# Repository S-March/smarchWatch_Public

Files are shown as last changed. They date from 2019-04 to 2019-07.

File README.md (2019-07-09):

# smarchWatch_PUBLIC

I decided sometime last year that I wanted to make a smart watch from scratch. I am an electrical engineer and product designer by day, so this was a fun side project that had been rolling around in my head for a while now. For future projects and progress pictures feel free to follow me on instagram @SamsonMarch

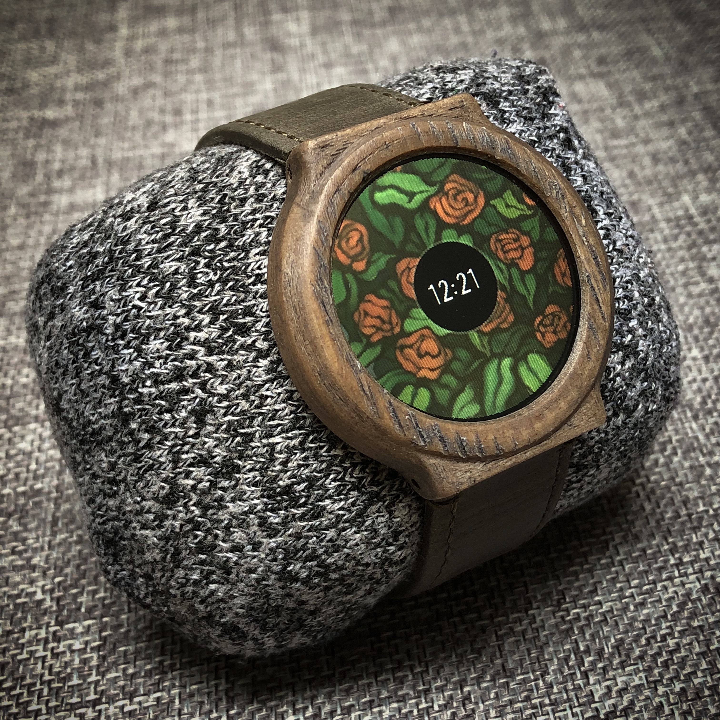
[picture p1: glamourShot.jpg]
smarchWatch


## Other Useful Links
To download the SDK for the DA14683, you can [click this link](https://support.dialog-semiconductor.com/system/files/restricted/DA1468x_DA15xxx_SDK_1.0.14.1081.zip)

If you want to order PCBs from the same place I did, you can [click this link](https://www.pcbway.com/project/shareproject/smarchWatch.html).

For more info on the build process and a blog describing the process, [click here](https://imgur.com/a/FSBwD3g).

For any ideas or things you wish could be in the project, comment on the issue [here](https://github.com/S-March/smarchWatch_PUBLIC/issues/15)

If you are interested in getting the soldered or barebones PCB, follow [this](https://github.com/S-March/smarchWatch_PUBLIC/issues/8) issue created by [vanabluca](https://github.com/vanbluca)

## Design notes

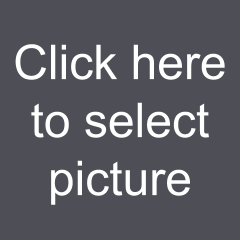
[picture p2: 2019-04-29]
Software/bitmapToArray/bitmapToArray/bitmapToArray/defaultPicture.png

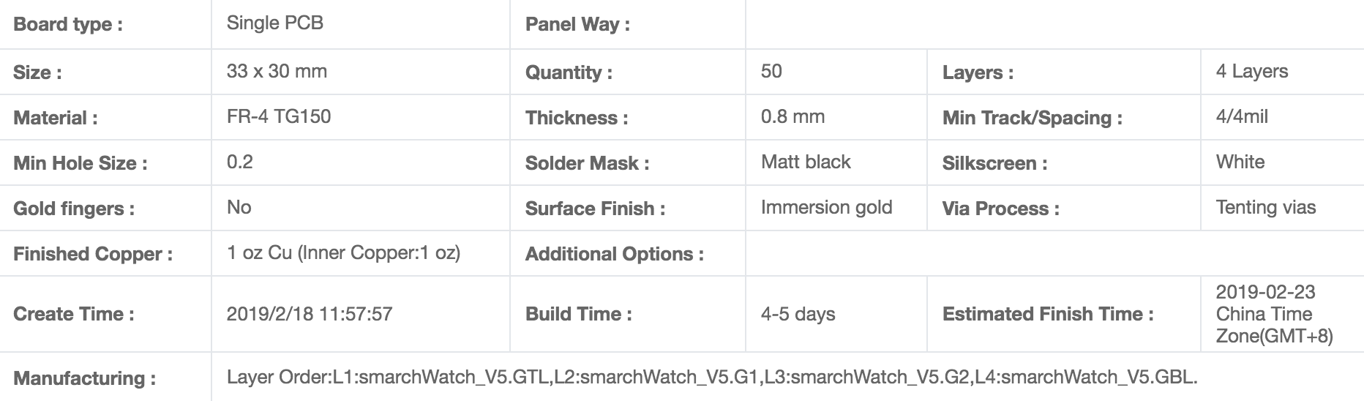
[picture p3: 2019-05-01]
PCB Files/Watch/Board parameters.png

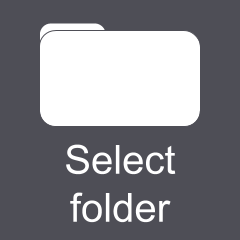
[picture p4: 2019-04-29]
Software/bitmapToArray/bitmapToArray/bitmapToArray/selectFolder.png

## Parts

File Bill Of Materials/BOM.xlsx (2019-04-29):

Comment | Description | Designator | Quantity | Part number | Digikey Number
10K | 0603 Resistor | R1, R3, R4, R5, R11 | 5 | RC0603FR-0710KL | 311-10.0KHRCT-ND
10uF | 0603 Capacitor | C2, C10, C11, C12, C15 | 5 | GRM188R61A106KE69D | 490-10474-1-ND
4.7uF | 0603 Capacitor | C3, C8, C9, C13 | 4 | CL10A475KP8NNNC | 1276-1044-1-ND
1uF | 0603 Capacitor | C4, C6, C7 | 3 | CL10B105KP8NNNC | 1276-1946-1-ND
100nF | 0603 Capacitor | C1, C5, C14 | 3 | CC0603KRX7R9BB104 | 311-1344-1-ND
5.1M | 0603 Resistor | R8, R9 | 2 | RC0603JR-075M1L | 311-5.1MGRCT-ND
330 Ohm | 0603 Resistor | R6, R10 | 2 | RC0603FR-07330RL | 311-330HRCT-ND
ECH8693R-TL-W | Mosfet Array 2 N-Channel (Dual) Common Drain 24V 14A 1.4W Surface Mount SOT-28FL/ECH8 | Q1, Q2 | 2 | ECH8693R-TL-W | ECH8693R-TL-WOSCT-ND
0 Ohm | 0603 Resistor | R13 | 1 | RC0603JR-070RL | 311-0.0GRCT-ND
0.1 Ohm | 0603 Resistor | R2 | 1 | RU1608FR100CS | 1276-6155-1-ND
0.39 Ohm | 0805 Resistor | R12 | 1 | RC0805FR-07390RL | 311-390CRCT-ND
2.2K | 0603 Resistor | R7 | 1 | RC0603FR-072K2L | 311-2.20KHRCT-ND
7M-16.000MEEQ-T | 16MHz ±10ppm Crystal 10pF 80 Ohms 4-SMD, No Lead | Y2 | 1 | 7M-16.000MEEQ-T | 887-1319-1-ND
9HT11-32.768KDZB-T | 32.768kHz ±20ppm Crystal 6pF 90 kOhms 2-SMD, No Lead | Y1 | 1 | 9HT11-32.768KDZB-T | 887-2616-1-ND
800-10-002-30-507101 | 2 Position Spring Mating Target Connector Surface Mount | P1 | 1 | 800-10-002-30-507101 | 1212-1446-ND
AML130A2402A | AML130A2402A Round 1.3" TFT Display | U1 | 1 | AML130A2402A | Dhgate.com
BQ29700DSER | Battery Battery Protection IC Lithium-Ion/Polymer 6-WSON (1.5x1.5) | U5 | 1 | BQ29700DSER | 296-43985-1-ND
C0720B001F | DC Motor Vibration, ERM 10000 RPM 3VDC | M1 | 1 | C0720B001F | 1670-1000-ND
CKP2012NR47M-T | Inductor_0805 | L1 | 1 | CKP2012NR47M-T | 587-2768-1-ND
DA14683 | SmartBond DA14683 Single-chip high-security Bluetooth 5 solution with expandable memory | U3 | 1 | DA14683-00000A92 | DA14683-00000A92CT-ND
ESD9B5.0ST5G | TVS DIODE 5V SOD923 | D1 | 1 | ESD9B5.0ST5G | ESD9B5.0ST5GOSCT-ND
LIS3DH | LIS3DH ACCEL 2-16G I2C/SPI 16LGA | U2 | 1 | LIS3DHTR | 497-10613-1-ND
RJD2430C1ST1 | Coin, 24.5mm 3.7V Lithium-Ion Battery Rechargeable (Secondary) 110mAh | BAT1 | 1 | RJD2430C1ST1 | 1572-1630-ND
W25Q128JVPIQ | FLASH - NOR Memory IC 128Mb (16M x 8) SPI - Quad I/O, QPI, DTR 133MHz 8-WSON (6x5) | U4 | 1 | W25Q128JVPIQ TR | W25Q128JVPIQCT-ND
PCB | PCB | N/A | 1 | N/A | N/A

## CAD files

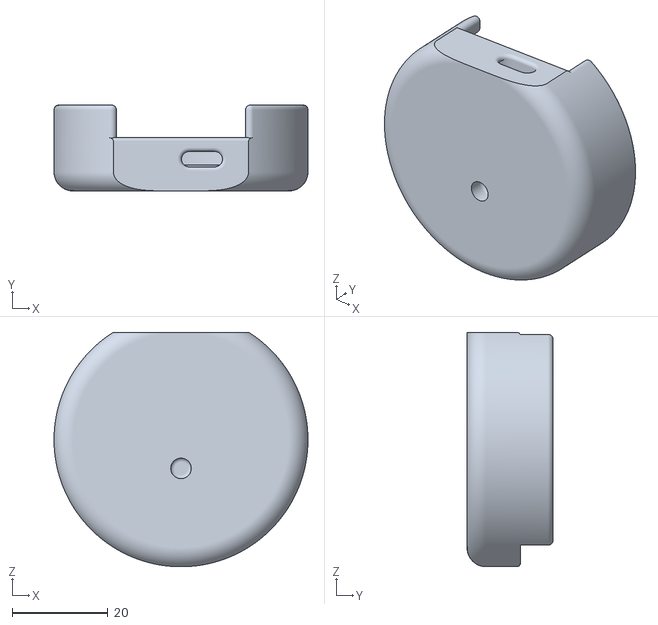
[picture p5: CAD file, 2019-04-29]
Housing/Charger/mainChargerBottom16mmBoard v13.stl
53.2 x 18.0 x 49.1

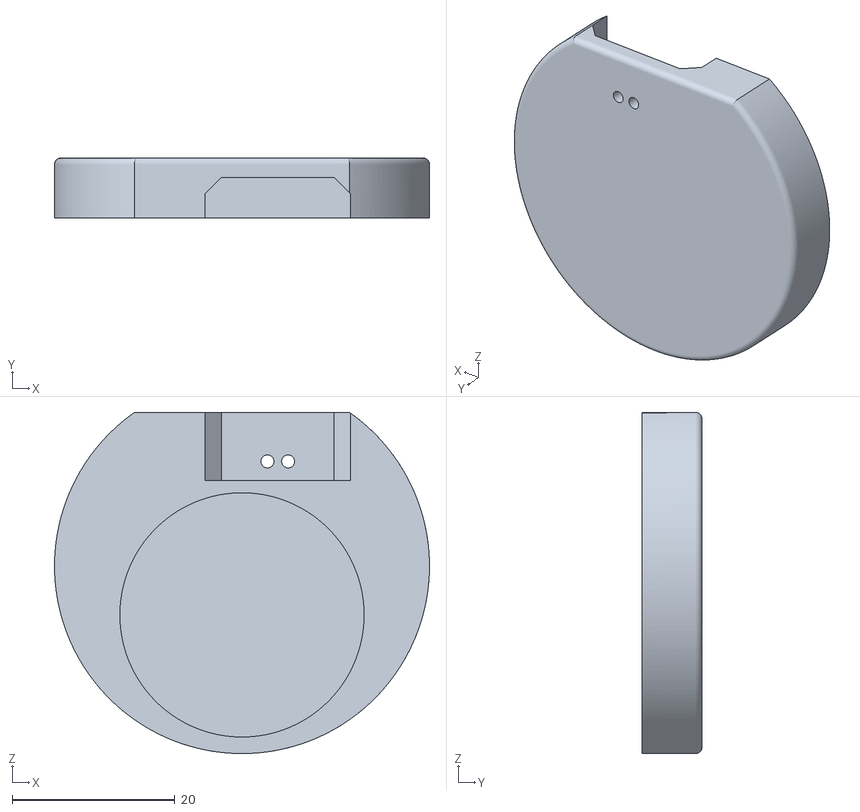
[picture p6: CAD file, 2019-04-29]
Housing/Charger/mainChargerTop v7.stl
46.1 x 7.40 x 41.9

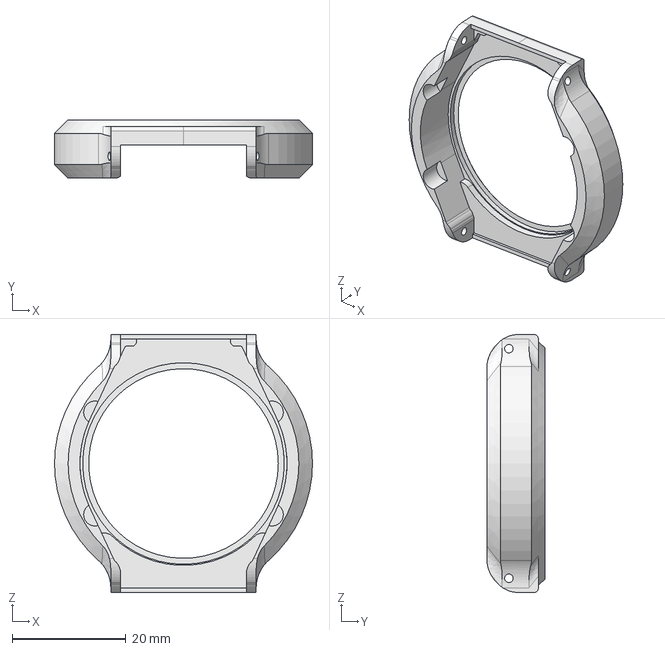
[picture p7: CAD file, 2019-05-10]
Housing/Body/bodyTop22mm_3.stp
45.5 x 10.3 x 45.5 mm

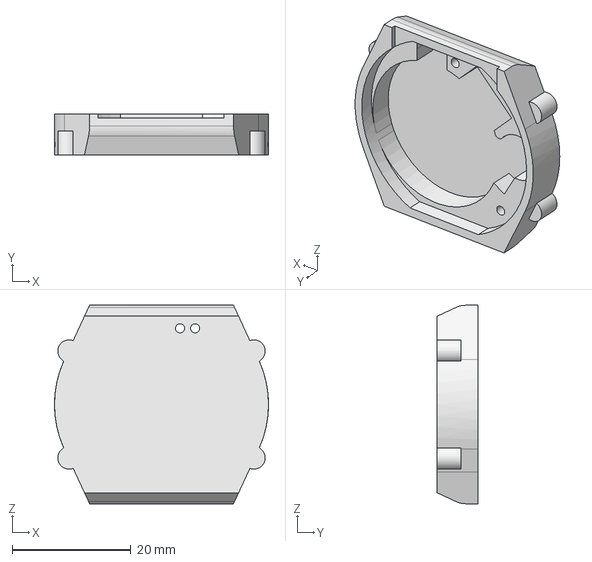
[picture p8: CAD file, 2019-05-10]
Housing/Body/bodyBottom22mm_3.stp
36.1 x 6.89 x 33.5 mm

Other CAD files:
Housing/Body/bodyBottom22mm_3.stl
Housing/Body/bodyTop22mm_3.stl

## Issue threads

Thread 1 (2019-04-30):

STEP/STP or IGES/IGS housing files?

justinclift, 2019-04-30:
Pretty nifty project. :smile:

With the housing files, any chance of STEP or IGES?

STL's are good for some things (eg 3D printing), but STEP or IGES include the model data, so are better for interchange with other cad software.

eg people can productively load a step or iges file in (say) FreeCAD and usefully modify it. :smile:

amishHammer, 2019-04-30:
Even and export of the Fusion F3D file would be helpful!!

vanbluca, 2019-05-01:
You can use the grabcad workbench to export the files in other formats really easily.

S-March, 2019-05-01:
I should be able to export them later tonight and put them up here!

S-March, 2019-05-01:
Didn't mean to close it. I will upload the files later tonight.

amishHammer, 2019-05-10:
> You can use the grabcad workbench to export the files in other formats really easily.

Yeah that's only good if you have a real solid model to put into grabcad.  With just the step file you can't do much conversion.

justinclift, 2019-05-10:
> With just the step file you can't do much conversion.

Typo?  The step file should be a solid model, whereas the stl file isn't real useful.

Well, as far as I understand anyway. :smile:

S-March, 2019-05-10:
Sorry I am just getting to this. The step files are now committed.

justinclift, 2019-05-10:
No worries at all @S-March, thanks for taking the time to get this stuff online. :grinning:

Closed 2019-05-10.

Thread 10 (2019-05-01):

Boom!

zerosimms, 2019-05-01:
This looks awesome!
Thank you so much for sharing and congrats on the Engadget publication!

Just one question, for the PCB board, can you tell me roughly how much it will cost? Or where I should begin to find out for myself - I can see it's not an "off the shelf" component and I'm assuming I would need to provide the PCB files to a manufacturer somewhere?

Sorry for the newbie question but normally I buy off the shelf, this part is all new to me.

Cheers

vanbluca, 2019-05-01:
I am looking into ordering a larger amount of PCBs at once to cut the costs. I already got some interested people. I expect 2pcs will be about $10 including shipping. Let me know in case you want one (or a few). I already got some interested people.

zerosimms, 2019-05-02:
Thanks, @vanbluca - I'd be very interested in purchasing, I'll wait for you ebay link :) Cheers!

Closed 2019-05-02.

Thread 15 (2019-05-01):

Wish list

S-March, 2019-05-01:
I thought it might be worth adding a wish list here for features that people might want. I may not have time to implement all of them, but maybe others in the community can!

vanbluca, 2019-05-01:
Would love a video on how to put your codes in the actual PCB.

Piflyer, 2019-05-01:
Hi, first off, congrats on creating this smartwatch! I lost mines, and I am desperate to find a replacement. I do like doing DIY crafts, but I would like to know if you could also support Android notifications. I think this would be very helpful since this project would then be supported by both platforms. I was wondering in the future, do you have any plans to make this more like Wear OS? I think that would be something very interesting to see happening. Thank you and have a great day!

abhinuvpitale, 2019-05-01:
Android Support?
Adding support for a touchscreen display - Resistive possibly?

anselm94, 2019-05-02:
Possibly a single framework for the watch. Then Android & iOS apps to communicate with the watch?

Anders0lesen, 2019-05-02:
This project certainly has my attention, but I would love to be able to use this as a G-Pay platform, which is pretty much the only reason I even am considering having a SmartWatch in the first place...

syphen, 2019-05-02:
Android Wear devices specifically use Snapdragon Wear chipsets. Would there be any advantages to building a device like this with something like the Snapdragon 670? (I don't know much about the hardware limitations or restrictions)

Also...swap out your display for a Transflective LCD so you can have the time visible with the screen "off".

trustbyte, 2019-05-02:
congrats for this project and making it opensource.

the biggest plus is i believe the software. clean and simple, no java, no siri, no bullshit.

if i were you I would try to get in touch with the guys that make the Raspberry. make it happen as a kit(no soldering), donate a part of the money and get some for yourself as you deserve it and let us get some fine smartwatch.

tutorials at all levels would be great to many. your work is awesome but many maybe can't get their head around the files and code without
some more details and clarifications.

the battery life of one week is great and while something life pulse sensor or anything health realated is nice it should stay away if the battery becomes 2 days max.

keep yourself healthy and don't stop innovate, we are grateful and courious of what can come next.

S-March, 2019-05-02:
Thank you so much!

I will try to provide some more guides and better descriptions of some of
the neats parts of the code in the coming days (if I have some time). I
really appreciate the thought about monetizing this, but I really like the
idea of it being free for anyone out there! As a kid I was always bummed
when I couldn't afford to work on a cool project.

Stay healthy yourself and I can't wait to see what awesome stuff YOU come
up with next! We are all creators and innovators in our own way.

Best,
Sam

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

jurkov, 2019-05-02:
Thank you for your work!
Is there enough space to add a LoRa IC for LoRaWAN communication?

adrienlesage2005, 2019-05-03:
Touchscreen or physical buttons, custom watch face support, music control, calculator, and a nice UI. Basically an open source Pebble killer :P

oeah2, 2019-05-05:
@S-March
I am an (junior) electrical engineer too and I like your idea.
I'd like to contribute to the project. Can we get in contact for this?

nh1402, 2019-05-05:
support for a bigger battery would be nice, the BL-S6 is the largest smartwatch battery that I'm aware of at 570mah (the LG Urbane 2nd Edition LTE battery), although it runs at a higher voltage at 3.85v.

pratikshiyal, 2019-05-06:
Would it be possible for you to share not just the gerber files but also the PCB and Schematic design files? this would enable the community to make any hardware modifications they like.

alextechcc, 2019-05-08:
Can you direct me to any materials you referenced / know of for that crazy antenna design?a

absint0o, 2019-05-16:
Heart rate monitor please!!! Congrats on the watch! A true open source flagship killer!

nicholaswagner, 2019-08-04:
A heart rate monitor would be awesome, but this project is fantastic!  Thanks for sharing!

dannygrob, 2019-08-30:
I'd love to have an extra connector for CTP on this display:
https://www.ebay.com/itm/1-3-inch-240x240-round-IPS-SPI-tft-lcd-display-with-CTP-for-smart-watch/112800854794

This wil open up so much more potential

boelle, 2020-07-27:
> This project certainly has my attention, but I would love to be able to use this as a G-Pay platform, which is pretty much the only reason I even am considering having a SmartWatch in the first place...

same thought here, why a watch when the phone can tell the time :-D

boelle, 2020-07-27:
> Touchscreen

would be usefull

boelle, 2020-07-27:
space for a rubber ring/seal between display and case and another one between the bottom and the case

would not make it a dive watch but would keep it more safe

boelle, 2020-07-27:
working with android would also be nice

> Android Wear devices specifically use Snapdragon Wear chipsets. Would there be any advantages to building a device like this with something like the Snapdragon 670? (I don't know much about the hardware limitations or restrictions)
>
> Also...swap out your display for a Transflective LCD so you can have the time visible with the screen "off".

neonot, 2020-11-13:
Now that you have got a smartwatch and smart-glasses. How about going smaller and make a smart attachment to go between conventional watch lugs and a strap? I have been toying with this idea for quite some time but not getting anywhere and looking for a buddy to discuss. This project would need a small OLED screen with intelligence and Li-poly battery. Something like [this but not fixed ](https://youtu.be/Y7s2CCg0KZY?t=508)to a band. I think it needs to go between the band and watch lugs (near side).  The hardware should all be available. The battery and charging circuit could slide under the actual leather or steel  strap/bracelet of the watch on the near side. One could enjoy both conventional watches with a smart OLED notification exactly where it is best visible.

Nightchicken, 2023-07-15:
I absolutely love this project and find it absurd that you spent so much time on this.

An app ecosystem, maybe like a git package thing to do it.

Also a dial like what the apple watch has for menu navigation.

I am definitely programming tetris for it when I get the chance.

Thank you for all the time you have spent on this project and then making it open source.

Whiteeeey, 2025-05-18:
I think this is a fantastic project that demonstrates what can be done with some simple equipment. Unfortunately, the ANCS notifications no longer work with ESP32 3.02 libraries, something to do with different advertisement and even when adjusted to allow the code to compile the esp32 does not appear on apple phones as a device but it does appear on android without the possibility to connect. I'm trying to see if I can get it working with the old bluetooth libraries but with little success. Has anyone else run into these issues or is there a way to easily work around this?

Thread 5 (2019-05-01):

Connectors for LCD and touch screen in the BOM?

cameronm191, 2019-05-01:
Hello,

I believe I don't see connectors in the BOM for the LCD and touch screen.
It's been a while since looking at a schematic and BOM, so if they are there I am sorry!

Great work!!! I'm very interested in building one!

cameronm191, 2019-05-01:
Never mind I found it on the LCD data sheet!

https://www.digikey.com/product-detail/en/hirose-electric-co-ltd/DF37NB-24DS-0.4V-51/H11850CT-ND/2230650

Closed 2019-05-01.

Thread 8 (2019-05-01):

Not enough info on PCB

vanbluca, 2019-05-01:
When I try to order the PCB I need to fill in a lot of info I can’t find anywhere (like thickness). Could you give us some more info on how to order the PCBs?

S-March, 2019-05-01:
Absolutely. Let me see if I can just take a screenshot of the parameters and upload it.

S-March, 2019-05-01:
There should be a picture with board parameters in the PCB folder now.

S-March, 2019-05-01:
I'm going to re-open the issue so people can see, I added a link to the main page where you can just have the same pcb maker make your boards for you. I set up all the files and parameters already, so you can just click "order".

https://www.pcbway.com/project/shareproject/smarchWatch.html

vanbluca, 2019-05-01:
I will order 100pcs and sell pcb kits (pcb for watch + pcb for charger) for $12 on eBay. I was thinking $2 of every sale will be donated to the maker. Worldwide shipping is $1.50, so total price is $13.50

Feel free to announce this on your github info page too.

S-March, 2019-05-01:
You're too kind! I will pin this issue and close it out so others can see it.

vanbluca, 2019-05-01:
This project is so great! I want to help as many people as possible recreating this!

vanbluca, 2019-05-01:
Perhaps you could announce it somewhere under “code” too? I can imagine not everyone reads “issues”

vanbluca, 2019-05-01:
I meant in the README.md document

abhinuvpitale, 2019-05-01:
Is this legit?

vanbluca, 2019-05-01:
Update: will be selling through eBay so you guys have buyer protection!

anselm94, 2019-05-02:
@vanbluca Please post the link once the eBay listing is ready. Fans like me are awaiting here 😃

edwinchenloo, 2019-05-02:
shouldn't you give time for a discussion of version 2 before ordering pcb's?   I for one would like an optical heart rate sensor.  Also, of more value to people would be the selling of already populated pcb's.  I don't have the soldering skills and equipment needed to do that.

vanbluca, 2019-05-02:
@anselm94 I will order them later this week an expect to have it in about 2 weeks from now. Will keep you posted

vanbluca, 2019-05-02:
@edwinchenloo I personally don’t think the maker has time to make a version 2 anytime soon. I may be offering fully soldered PCBs later too, but these will be much more expensive (an additional $25 dollars for the components i have to solder on it and I will have to charge you for the time I spend on soldering)

vanbluca, 2019-05-02:
PCBs have been ordered

abhinuvpitale, 2019-05-03:
I agree with @edwinchenloo, I think there is a need for soldered components rather than bare PCBs, because that's thekey bottleneck here.

exploshot, 2019-05-03:
Will you add a Link here? Total costs then 40$?

vanbluca, 2019-05-03:
@abhinuvpitale I guess I will be offering soldered PCBs too, but that will take some more time since I am currently quit busy

vanbluca, 2019-05-03:
@exploshot I will definitely add a link here to the listing for the $12 PCBs. As for the $40 did you mean that is for the unsoldered PCBs + spare components or for the fully soldered PCBs? I hope you understand I can’t solder it for $3...
I am not sure yet if I will be offering an option to purchase bare PCBs + the required spare components. This is because I would have to order lots of components with the risk of ending up not selling them due to lack of interest.
You can also simply order the components here: https://www.digikey.com/short/pzz59b
(Please note: battery not included!)

Blue-Dust, 2019-05-05:
I am interested in building one, but how experienced do you need to be for the soldering?  I am expecting it to be quite small/intricate job.  I am not ready for that type of work yet.  Also, I read somewhere this is only working on iPhones (post/comment).  I have an Android phone and would hold off until I knew it was compatible.  I would also want to buy a kit, or easy links to order everything so I don't buy the wrong stuff.  Good idea on selling the boards on eBay.  I would be more willing to buy into this project with that option. Is there a video showing how to use it and it's current features?

vanbluca, 2019-05-06:
@Blue-Dust as for the soldering, it is not like soldering with a soldering iron. This video shows the technique used for it: https://youtu.be/qyDRHI4YeMI. The watch is indeed currently for iPhones (I assume since the maker @S-March has an iPhone and not and android phone). Perhaps @S-March decides to make and wondrous version too (if he has time) since lots of people mentioned (in issue #15) they would really like a version that supports android.
As for kits/links please wait a little longer and I will prepare this for you guys. PCBs will listed on eBay once I have them (I expect in about 2 weeks).
All the pics, vids and info that are out there are in this github page and the imgur page. As for the current features it is pretty straightforward; it is basically a digital watch that forwards notifications from your phone.

vanbluca, 2019-05-06:
Here are some links for the components:
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
trisimix, 2019-05-17:
I'm gonna buy one @vanbluca some people I know too maybe

trisimix, 2019-05-17:
Just need to figure out everything else I need, the electronics obviously, but the tools needed to place them as well

pratikshiyal, 2019-05-18:
@vanbluca  the listing in eBay has been removed? Or are you out of stock?

vanbluca, 2019-05-18:
@pratikshiyal no I am not out of stock and the listing is still online. Perhaps this link works: https://rover.ebay.com/rover/0/0/0?mpre=https%3A%2F%2Fwww.ebay.com%2Fulk%2Fitm%2F254232630219

vanbluca, 2019-05-18:
In case you can still not find it:
1. Go to eBay.com
2. Search: smarch watch
3. Check eBay doesn’t auto correct it to “smarth watch” or so
4. The listing should appear now

vanbluca, 2019-05-18:
@trisimix that is great to hear! As for the components and tools, here are some suggestions. When there are more options (for example A and B), you can choose either one of them.

Here are the components I ordered:

1 Electronics for PCBs (watch+charger): https://www.digikey.com/short/pzb540

2A. Battery (US only)(recommended): https://www.digikey.com/products/en?keywords=1572-1630-ND
2B. Battery (outside US & cheaper alternative): https://m.dhgate.com/product/5pcs-1-lot-lir2430-3-6v-lithium-li-ion-rechargeable/409686938.html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

3A. Display (eBay): https://rover.ebay.com/rover/0/0/0?mpre=https%3A%2F%2Fwww.ebay.com%2Fulk%2Fitm%2F112839389316
3B. Display (DHgate): https://m.dhgate.com/product/aml130a2402-1-3-240-240-inch-round-tft-lcd/413657684.html?invitorid=3uqYbq50

As for the display, I recommend to go to the eBay listing and ask the seller to ship it as a letter in an envelope since this will cut shipping costs, import charges and administration costs for the import charges.

Tools:

1A. Reflow oven (for soldering):  https://s.click.aliexpress.com/e/OP5p41xpv
1B. Rework hot air gun (cheaper alternative for reflow oven): https://s.click.aliexpress.com/e/bNyNkmh5p
1C. Skillet method (see message from @amerello above):

2 Solder paste: https://s.click.aliexpress.com/e/kgqmfXvGX

vanbluca, 2019-05-18:
I forgot to mention, but I will be abroad between May 23 and May 30. I won’t be able to ship anything between those 2 dates.

kamshee, 2019-06-11:
@vanbluca Any option for soldered PCBs? If not are the stencils available with the pcb listing? Thanks.

abhinuvpitale, 2019-06-19:
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

The digikey list is not showing the right components, it shows incorrect part number, could you please check that?

Ajayrulez, 2019-07-20:
This is great. I got all of BOM ordered and shipped to LA.

saurabhreigns, 2019-08-29:
Electronics for PCBs (watch+charger): https://www.digikey.com/short/pzb540
Checked the list items and I am unable to find U1 (in bom designator)  it is supposed to be a 24 pin receptacle for LCD which is to be soldered onto the PCB. I ordered these items form digikey:
1. CONN RCPT 24 POS SMD Gold H122178DKR-ND
2. CONN RECEPT 10 POS 0.4mm SMD -BM14B(0.8)-10DS-0.4V(53)CT-ND
and the parts i received are not correct. they have 28 and 14 pins without metal fittings. Moreover , under a microscope i could see that they will not mate with the lcd connector. Can someone please help with a link to purchase correct female mating connector for the lcd. Supplier from India will be preferred.

[Images.zip](https://github.com/S-March/smarchWatch_PUBLIC/files/3554406/Images.zip)

dannygrob, 2019-08-31:
I think the display connector is: ‎H11850CT-ND‎ from Digikey

d3mon187, 2019-12-11:
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

@vanbluca  Haven't heard from you on ebay, and was wondering if you missed my pcb purchase, or managed to ship it out yet?  I'm not an avid ebayer so I would understand.  Thanks!

darshanys, 2020-02-13:
Is anybody selling populated PCB board yet?

vm41, 2020-10-22:
@S-March can you mention values of pi network components?

S-March, 2020-10-22:
@vm41 no need for any. You can drop in a 0ohm resistor in the series element or just blob some solder and make a bridge!

vm41, 2020-10-22:
> @vm41 no need for any. You can drop in a 0ohm resistor in the series element or just blob some solder and make a bridge!

Ok. Thank you!

vm41, 2020-10-26:
@S-March  Are the board parameters for charger and watch the same?

S-March, 2020-10-26:
@vm41 It's a 2 layer board. But otherwise, yes.

vm41, 2020-10-29:
> I'm going to re-open the issue so people can see, I added a link to the main page where you can just have the same pcb maker make your boards for you. I set up all the files and parameters already, so you can just click "order".
>
> https://www.pcbway.com/project/shareproject/smarchWatch.html

Are charger files also included in above link?

S-March, 2020-10-29:
@vm41 No. Unfortunately, I could only set 1 board per project.

Closed 2019-05-01.

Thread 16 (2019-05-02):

Freediver and scubadiving watches

juliankauai, 2019-05-02:
Watches for underwater use seem way overpriced and lack normal smart watch features. Regular companies like Apple and Google aren't likely to near guaranting the depths that Freedivers dive to generally 100 to 400 ft. We have always wanted more sound alarms, brighter displays and features especially for freedivers and scuba divers.

Please consider work/experimentation in this area. Currently 99% of watches are old style and lack any smart watch features.

Thanks, it's wonderful to hear about your project.

edwinchenloo, 2019-05-02:
For scuba purposes, one better rely on something commercial.  Why risk relying on something homemade while at great depths?  Having said that, finding a 25-50m waterproof case would make it ok for recreational swimming and surfing.  The original case used wouldn't even be ideal for when showering or light rain.

boelle, 2020-07-27:
my comment here might solve the issue with light rain and showering: https://github.com/S-March/smarchWatch_PUBLIC/issues/15#issuecomment-664059135

of course case has to be wathertight itself

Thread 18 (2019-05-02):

All about the housing

vanbluca, 2019-05-02:
Some of you may be interested in printing the components in wood too. I personally like the finishing on this 3D print: https://imgur.com/gallery/yJAAS

Thought I should share it with you guys since it may be useful.

Feel free to post more tips for the finishing below

vanbluca, 2019-05-02:
It may also be cool to make the watch in metal and apply a cool finish. You would possibly have to apply some sort of isolation to the inside of the watch to avoid shortcuts, but that shouldn’t be too hard.
I.materialise offers an option to order components in all kinds of metal (even in 18K gold!). I personally like the brass option since they are offering really good lookin surface finishes (18k yellow or red gold plated, chrome plated, rhodium plated and (perhaps one of my favorites) black color plated. You can read more about it and find examples right here: https://i.materialise.com/en/3d-printing-materials/brass/colors-finishes

Unfortunately, ordering them in metal isn’t exactly cheap. For instance, the watch body top would be €99.01 and the watch body bottom would be €67.94 excluding VAT. when ordering them in brass (with black color plating and polish). Since the company is based in Belgium, the VAT should be 21% (I assume they apply this on orders from all over the world). This would make the body of the watch cost €166.95*1.21= €202.01 (about $225).
This is indeed expensive, but I believe it brings the watch to a whole new level!

S-March, 2019-05-02:
You also would need to be careful with the antenna. You may end up attenuating too much signal with a metal case.

skintigh, 2019-05-02:
Did you consider making them out of actual wood on a CNC machine?

S-March, 2019-05-02:
If I had a CNC, I wood** have!

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

skintigh, 2019-05-03:
I had access to one until mid April... Hopefully in September I will again and could give it a shot.

Will you be selling kits?

vanbluca, 2019-05-03:
@skintigh I will be selling kits for the bare PCBs (I ordered 100pcs so you can all benefit from bulk prices). As mentioned before, $2 of every sold lot will go to @S-March to support him. You can read more about it in issue #8. I will maybe also offer soldered PCBs at a later stage for an additional charge since lots of people seems to be interested in this.

With the fully soldered PCBs you will only have to order the screen, battery and make a casing (I could 3D print it too on request). Then all that is left to doo is put the coding in the PCB and assemble it. I think fully soldered PCBs are already quit close to kits...

davidkraus13, 2019-05-05:
Hi, I want to try make one housing at CNC, can you share 3D model in something else then .stl? it will be better for CAM preparation.

vanbluca, 2019-05-05:
@davidkraus13 please download the STL files. Then upload the files to your grabcad workbench. From there you can export it in the format you want.

davidkraus13, 2019-05-05:
Unfortunate from STL is conversions bit of pain, but I will find way

vanbluca, 2019-05-05:
@davidkraus13 what file format do you want?

davidkraus13, 2019-05-05:
STEP will be perfect, or original file from your cad, Im using Rhinoceros so Im able open lot of files. Unfortunately STL is similar like you save DWG drawing to JPEG you make "raster" from model. It works fine for 3D print, but for CAM purposes is far from optimal.

vanbluca, 2019-05-05:
I will try to convert it for you later today.
For the original file from CAD only the maker @S-March will be able to help you

davidkraus13, 2019-05-05:
Hi, Finally I decide to remodel housing, I pull request to merge to master. Inside features shut be same, bit different outside design.

S-March, 2019-05-10:
Original cad step files are now committed.

Closed 2019-05-10.

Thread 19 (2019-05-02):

Battery only ships in US (solution)

vanbluca, 2019-05-02:
The battery RJD2430C1 is manufactured in the US and can’t be shipped outside the US due to restrictions. This battery should work as well (but unfortunately they have a smaller capacity): https://m.dhgate.com/product/5pcs-1-lot-lir2430-3-6v-lithium-li-ion-rechargeable/409686938.html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
Any other “LIR2430” battery that is 3.6 or 3.7V should work too

S-March, 2019-05-10:
I am not entirely sure this works. The part that I linked has two "legs" that are used to solder to the underside of the board. I would order the Illinois capacitor part to be sure.

vanbluca, 2019-05-11:
I would defenitly prefer to order the Illinois capacitor battery as well, but that is not an option for everyone. The battery contains lithium which leads to shipping restrictions and therefore they won't ship it outside the US. For those we live outside the US, we need to find a solution and ordering a battery from china/hong kong seems to be the best options
I guess we would have to make the "legs" ourselves. This could be made out of a very thin tin sheet. You may need to isolate some parts of the legs or battery in order to avoid shortcuts. This can easily be done with nail polish.
Another option is that someone located in the US orders a bunch of these batteries and ship them as a letter (probably without tracking code) outside the US. I would highly appreciate it if someone could order one or a few pcs for me and ship it in an envelope to The Netherlands. For contact: l.vanbeers@icloud.com

jspoe, 2019-08-01:
+1 Would like to know where to get this battery in europe too, of have someone to ship it to me from the US.

jspoe, 2020-01-27:
For those who are looking for someone who ships the listed battery outside of the US (ground shipment):

https://nl.aliexpress.com/item/4000548851959.html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,searchweb201602_3,searchweb201603_53

Closed 2019-05-10.

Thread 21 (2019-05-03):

Power concumption ?

JPB1JPB1, 2019-05-03:
Great project

which is the power consumption in running mode with/without screen ?

How is it precise for the clock after one day of running , still secondes or minutes without update from other device under bluetooth ...

uSD card support for video ?

Bravo
Jp

S-March, 2019-05-03:
Power consumption is about 6mA when the screen is off but the device is in active mode, with the screen on its about 15mA.

There is a 32K crystal on there, so it’s pretty accurate, seconds of drift if that (per day).

No uSD card, unfortunately, that takes up too much space.

Closed 2019-05-03.

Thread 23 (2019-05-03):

Not enough info on components for charger

vanbluca, 2019-05-03:
Some of the components for the charger are not listed in the “bill of material”. For example the magnet (locks watch in place) and the (female) connector that is for the cable that goes into the charger. Perhaps other components for the charger PCB are also missing, but I am not sure about that.
Could you please add the missing info? As for the magnet could you give us at least the dimensions?

vanbluca, 2019-05-03:
Thx!

vanbluca, 2019-05-04:
According to the “schematics” files, you will need the following additional components for the charger (all just 1 piece):
10118194-0001LF (609-4618-1-ND)
ESD9B5.0ST5G (ESD9B5.0ST5GOSCT-ND)
825-22-002-10-001101 (ED10660-ND)

I recommend to wait with ordering them until @S-March confirmed. Perhaps @S-March could also tell us the dimensions of the magnet he used.

S-March, 2019-05-10:
Those are the correct parts. Also this is the magnet I used:
https://www.amazon.com/gp/product/B074BP1FR8/

vanbluca, 2019-05-11:
I was surprised to see you used a 32mm magnet while the space in the body is just under 30mm. I would personally go with a 30*5mm or a 25*5mm magnet.

S-March, 2019-05-11:
There is no magnet in the actual watch. It is just in the charger.

vanbluca, 2019-05-11:
Yes I know. I was talking about the space in the housing of the charger...

Closed 2019-05-10.

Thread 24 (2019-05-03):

BEWARE: POSSIBLY WRONG SCREEN LISTED IN BILL OF MATERIALS

vanbluca, 2019-05-03:
According to the “bill of materials” you will need a AML130A2402A screen. If you search for this model, you will probably find this one: https://m.dhgate.com/product/aml130a2402a-1-3-inch-240-240-round-tft-lcd/413771628.html?invitorid=3uqYbq50
In one of the gifs/videos from the Imgur page, you can see the used LCD screen (see attached picture). When you have a closer look at it you see it has only one connector instead of 2. This would mean the screen listed as “AML130A2402A” is the wrong model since that one has 2 connectors (and some other small differences). I think the right screen is being sold as “AML130A2402” (not the “A” at the end). Here is a link: https://m.dhgate.com/product/aml130a2402-1-3-240-240-inch-round-tft-lcd/413657684.html?invitorid=3uqYbq50

I recommend you guys not to order any screens until @S-March has replied to this. In case you already ordered the screen you may want to consider canceling it (if possible).
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

S-March, 2019-05-03:
Hmm...

The display manufacture (Amelin) lists it with the “A” at the end in their catalog.

http://amelin.com.cn/en/pd.jsp?pid=381&mid=339

But you are correct, you want the one without the touchscreen/extra connector.

vanbluca, 2019-05-03:
Yeah that’s weird.
Anyways, these should be the right ones:
https://m.dhgate.com/product/aml130a2402-1-3-240-240-inch-round-tft-lcd/413657684.html?invitorid=3uqYbq50
https://rover.ebay.com/rover/0/0/0?mpre=https%3A%2F%2Fwww.ebay.com%2Fulk%2Fitm%2F112839389316

vanbluca, 2019-05-03:
@S-March it would be nice if the watch supported touchscreen though.

S-March, 2019-05-03:
I made a conscious choice not to include it. I felt that touch just doesn’t work for a screen so small. If others want to include it, that it totally up to them, that’s why the files are open source! :)

vanbluca, 2019-05-03:
I have to say I agree. Btw, could you please also have a look at issue #23

vanbluca, 2019-05-16:
Tip for ordering the LCD screen:
I recommend to contact the seller and ask to ship it in a letter. This cuts both the very high shipping costs ($41) and import charges. Also their shipper (DHL) asks $20 administration costs for the import charges. This means you would have to pay $10+$41+$20+import charges for only 1 LCD. When they ship it in a letter, shipping will definitely be way less than $41. Also most companies put a value like $5 on an envelope so you won’t have to pay any import charges and administration costs!

Closed 2019-05-10.

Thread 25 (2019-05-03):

Loading sofware

amerello, 2019-05-03:
Congratulation @S-March on this awesome project. I've looked at the very inspiring blog that you wrote and the repository, but I wasn't able to see how you transfer the software to the watch. Through the charger interface you only provide VBUS. Is this done via BT? If so how do you activate/deactivate the programming mode?
Many thanks again for the awesome write up.

vanbluca, 2019-05-03:
@amerello I totally agree! In issue #15 I mentioned I would highly appreciate it if @S-March could make a video on how to put the coding “in the PCB”.

bdcooke, 2019-05-16:
I too, would love to know how to program this. We got the code. great, I have no idea how send it to the board.

abisheksethu, 2019-05-18:
As far as I understood, the watch schematic explains about header pads which have UART TX and UART RX (connected to B23 and A35 of DA14683). Using that, we can flash binary (QSPI built) to the memory device using the dialog software tool via USB. Also, we have to use the respective voltage levels for connections (connectors/cable), like A35 and B23 might be 3.3V (TTL range) and USB of PC might be different.

amerello, 2019-06-12:
Thanks @abisheksethu that makes sense! That also means that the programming interface USB to VBUS, RX, TX and GND is not yet documented in this repository. RX, TX and GND are on the top left corner of the first layer, that would probably be the place for a connector

jacobandersson86, 2019-08-15:
I cannot manage to upload my binaries. I'm trying to do this with serial. I'm using at FTDI and the TX RX pads on the PCB.

I'm trying to flash using the "External tool" called "program_qspi_serial_win".  The console tells me it can upload the bootloader but it cannot verify RAM.

If I set up a serial terminal (in my case PUTTY) I get the message "DA14683" written 4 times, just as described in the getting started tutorial on Dialoge Semiconductors.

@S-March Can you please give me some small hints here. What setup did you use in order to program you watch? I am so close right now. I've 3d printed the case, I´ve built the PCB, I've waited a million years for the battery and display to be delivered. Soo close....

S-March, 2019-08-18:
Hi there @jacobandersson86! Sorry it's taken me a while to get back. You will need to load the code over JTAG using the other set of 4 pads. You can hook up the JTAG lines to the SWD, CLK, RST and GND pads.

jacobandersson86, 2019-08-21:
No worries @S-March. I am so thankful that you are taking your time. I am using SmartSnippets Studio and I am getting my J-link to connect now.

I do still have some problems though. I am still unable to program and I can't read. It could of course be a bad soldering or similar.

I just have some questions to sort out some of my issues for the troubleshooting.

Q. How do you get the Vref for your JTAG device? I am using a Segger J-link and it needs V-ref to accept the connection. I'am also powering my watch from the batterypads at the moment since I don't have soldered the battery yet, hence I am using the VBUS also as my reference voltage for the J-link.

Q. Are you using the SmartSnippetsStudio and the external tool called "program_qspi_jtag_win"? That is how I try to program the watch. I´ve also tried the tool from segger called J-Flash, but there are no presets there for the flash memory, so I didn't manage to flash with that tool either.

Q. What bootloader file are you using? When I start the programmer in SmartSnippets Studio mentioned above, it says "bootlader file not specified, using internal uartboot.bin"

Many thanks in advance

rickmaity, 2019-09-02:
@jacobandersson86 have u found any solutions to your problem ....?

jacobandersson86, 2019-09-04:
Hi @rickmaity,
Unfortunatley I haven't. But I haven't had time to investigate this further.

I think the key is to use the correct Vref for you J-Tag device. SWD needs SWCLK, SWIO, GND and Vref. In this project, the Reset has been populated as a pad, probably indicating that the reset needs to be controlled as well. I've tried finding a hardware reference guide for the SWD interface without success for this microcontroller. I might have some more time for this later this week. I'll get back if there is any success.

dannygrob, 2019-09-13:
@S-March +1 I'm also ready, pcb populated and tested, but somehow It won't recognize the ic. Connected the SWD to this pinout IO/CLK/RST/GND of the mini:

https://www.segger.com/fileadmin/images/products/J-Link/Accesory/Adapters/J-Link_9-pin_Cortex-M_Adapter.png

dannygrob, 2019-09-15:
Ah I got it to work. I connected VREF to VBAT (r6 i believe) and the 5v from the jtag to the vbus (not sure if this is needed). I got it to compile, upload and run the code, and the device shows up on my iphone as 'smarchwatch'. I can't get anything to display, but I did not upload any images yet (not yet sure how, and missing the font image)

Dirty-table, 2020-01-09:
Hi, I've been trying to build this smart watches for quite some time, but now I'm stuck at following problem and I need help with it:

Once I connect programmer to the PC, it gets correctly recognized. But when I try to connect to it via J-link GDB server I get an error message: "WARNING: RESET (pin 15) high, but should be low. Please check target hardware." The program is constantly pulling RESET pin to high, once I launch it, no matter what I do. I've tried disconnecting RESET pin, which resulted in different error message saying that it cannot open GDB interface, and start GDB server.

Thank's for your help.

dannygrob, 2020-01-09:
Hi,

Using smart snippets and the build in debugging I did not use GDB server at all I believe. I load the software using the 'scripts' you have to include (you need to follow the tutorials and getting started, see https://github.com/S-March/smarchWatch_PUBLIC/issues/37, esp the getting started https://www.dialog-semiconductor.com/sites/default/files/um-b-047-da1468x_getting_started_7v0.pdf and section 8.3 Software Build)

I use the program_qspi_jtag to load the firmware, then use Ozone (included in the smartsnippets environment) to restart and debug.

Hope that works.

BTW I rewrote the whole smartwatch code and made a new case for it..., if anyone is interested :)

Dirty-table, 2020-01-12:
Hi,

I've tried loading firmware through program_qspi_jtag_win, but every time I do it, I end up with error message: cannot open gdb interface. Any tips on what should I try next?

Thank's for the answer.

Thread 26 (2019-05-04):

Panelized stencil file.

vanbluca, 2019-05-04:
@S-March could you put a few copies of the stencil files in a single document?
Let’s say the stencil can be 400*240mm big. Could you put like 8 copies on the 400mm side and 5 copies on the 240mm side (so there are a total of 40 copies in a single 400*240mm stencil). This will cut the costs a lot!

S-March, 2019-05-10:
I will see what I can do. I am not sure I can do that within the next few days, but I will try.

vanbluca, 2019-05-11:
@S-March it would be highly appreciated! This way I could order 40 copies for a total $40 instead of $6 each! These stencils will be listed on eBay along with the PCBs (which have been shipped out today!).

ppyuri, 2019-06-04:
Hi @S-March, I really love your work. It is so thoughtfully designed without excess and beautiful. I want to build my own Smarch Watch! I'm just concerned about the soldering portion as I'm just beginning to get into electronics. Sorry for the beginner questions. How do I get a stencil for the watch and charger?

@vanbluca I saw your ebay posting for the boards and will probably purchase from you. Are these stencils available yet?

Semperubi77, 2019-10-15:
anyone know if the stencils are available?
Thanks

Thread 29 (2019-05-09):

BOM doesn't have the antenna caps and inductor

bdcooke, 2019-05-09:
I don't see the parts for C16, C17, and L2 in the BOM. In the schematic they are unlabeled, connected to the antenna. Are they unpopulated? did you just solder bridge the inductor pads?

S-March, 2019-05-10:
That is correct. They were unneeded. The inductor pad can either be a solder blob or a 0Ohm jumper. They are 0402 size pads.

Closed 2019-05-10.

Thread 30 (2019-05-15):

Include updated BOM with pricing.

babarrett, 2019-05-15:
I looked up the Digikey prices for the BOM parts. I know these can change over time, but I added them to the BOM.xlsx file.
Worthwhile, I think, to give people an idea of the cost to build.

(Enclosed)

[BOM.xlsx](https://github.com/S-March/smarchWatch_PUBLIC/files/3184606/BOM.xlsx)

vanbluca, 2019-05-16:
Have you also added the components for the charger in it (they are not listed in the current version).
I described in issue #23 what components are needed (I believe it were only 3 components). In an updated version of the BOM.xlsx file I would really see those items added to it to avoid people buy not enough components.

babarrett, 2019-05-16:
Got it. Here's the new file.
[BOM.xlsx](https://github.com/S-March/smarchWatch_PUBLIC/files/3185580/BOM.xlsx)

vanbluca, 2019-05-16:
@babarrett thanks a lot! Would be great if @S-March updated the old one with this new version.
Oh and, not entirely necessary though, but you could also add the link to the eBay listing of the PCBs (https://ebay.us/FQBGIs) and the eBay link of the LCD screens (https://ebay.us/zBfP2e) under the “DigiKey number”. This could clarify the source.

Side note for ordering the LCD screen:
I recommend to contact the seller and ask to ship it in a letter. This cuts both the very high shipping costs ($41) and import charges. Also their shipper (DHL) asks $20 administration costs for the import charges. This means you would have to pay $10+$41+$20+import charges for only 1 LCD. When they ship it in a letter, shipping will definitely be way less than $41. Also most companies put a value like $5 on an envelope so you won’t have to pay any import charges and administration costs!

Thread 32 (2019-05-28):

Design files in some other format

emosenkis, 2019-05-28:
Would you be able to export the design files from Altium in some other format? I'd like to play around with adapting it for the capacitative touch variant of the display but I don't have an Altium license - I'd be looking for something I could import into one of the free or hobbyist-level PCB design softwares such as KiCAD, EasyEDA, Eagle, etc.

S-March, 2019-05-28:
Hopefully someone else can do this for you. I unfortunately don't have the ability to do so at the time. I made sure to export the schematics as PDFs so if someone wanted to recreate them in another format they could.

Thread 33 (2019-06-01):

3D print stencil cutouts

Fl4zher, 2019-06-01:
Hi, nice project!

Is it possible to 3d print stencil cutouts?

S-March, 2019-06-03:
I'm afraid the pads for the microcontroller will be too small for a normal printer to get right (resolution wise). Additionally, you would like to keep the thickness tolerance of your stencil extremely tight so that you don't over/under apply paste. Services like OSHStencil can get you an excellent stainless steel stencil for very cheap.

Closed 2019-06-03.

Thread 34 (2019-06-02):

Something interesting in Schematic file

ValentiWorkLearning, 2019-06-02:
In  Schematic file I noticed, that display's WR pin has't any connections on board and display driver uses the 9-bit SPI for transfering data between display  and MCU.
In ST7789V datasheet I've found that WR pin used for selecting, what would be transfered - command or data.
So, Why do you use the 9-bit SPI for display communication and where you find information about the display's interface?
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
I've created this issue because have a similar display, but haven't got any succesful results because trying to use 8 bit SPI with selecting data and comannd with toggling the WR pin.
Thanks for answer!

S-March, 2019-06-03:
Hi there!

I actually ended up using 9-bit SPI because I spent two weeks trying to get the display to work with the Data/Command line toggle and it wasn't working. I was banging my head against the wall and after pouring over the datasheet for the driver, noticed it had the option to do 9-bit SPI. The display would pick either 3 wire SPI, 4 wire SPI, a parallel approach or use of the Data/Command lines depending on how some internal (to the display). I had been looking at the data packets on my logic analyzer and couldn't find anything wrong with what I was doing.

Since I had nothing to lose, I tried the 9-bit approach and voila! The initialization code I had ran and my display turned on.

The only way I figured it out was by dumb luck. There was no documentation for it anywhere.

Page 33 of [this datasheet](https://www.newhavendisplay.com/appnotes/datasheets/LCDs/ST7789V.pdf) talks about the selection of the communication mode and then page 63 talks about how to pack the data.

Hope that helps!

ValentiWorkLearning, 2019-06-03:
Thanks a lot for your answer!
Therefore, interface with 3 and 4 wires is true random that defined only by display vendor.
I'll try one more with 9-bit SPI. Think, it must be successful. Thank you!
It will be nice, if I could contact with you on Facebook/etc, if possible.

ValentiWorkLearning, 2019-06-05:
Please, may you attach the waveform from logic analyser for unit sequence?

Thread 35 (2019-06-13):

Antenna

jacobandersson86, 2019-06-13:
I assembled and soldered the PCB tonight. I noticed a few discrepancies in the material for example that the connector for the screen was missing in the BOM and that some other components were not populated. I perfectly understood why there weren’t any component values for the PI matching net for the antenna, but is that little blub the antenna itself or are you supposed to solder on a small wire or similar to use as antenna??

Q. Are you supposed to add an antenna?

Another thing I can’t get my head around. The glass you are using, did it come with the screen? My screen hasn’t arrived yet and unfortunately I ordered the one with touch. Will give it a try and see
If it can be used whiteout having the cable for the touch conntcted.

Q. Do I need to buy/make a glass?

Many thanks for the time you spent on this awesome project. If I manage to program my pcb in the coming week/weeks then I will contribute with the programming tutorial many has asked for.

All the best!

abisheksethu, 2019-06-14:
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
**DF37B-24DP-0.4V(51)** - connector for screen without touch. isn't the right connector ?

S-March, 2019-06-14:
Hi @jacobandersson86

With regards to the antenna, you will need to solder a piece of wire to the half hole - 31.25mm in length.

You are absolutely right, I forgot to include the watch glass. It can be found here: [35mm diameter 0.8mm thick](https://www.esslinger.com/watch-crystal-flat-round-mineral-glass-crystal-80-mm-thick/). It should cost $1.25 I believe.

As for the connector, @abisheksethu is correct. It is the [mating part](https://www.digikey.com/product-detail/en/hirose-electric-co-ltd/DF37NB-24DS-0.4V-51/H11850CT-ND/2230650) for the one on the display.

jacobandersson86, 2019-06-17:
Nice, thanks for the help and the quick replies!

Closed 2019-06-17.

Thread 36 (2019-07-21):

Correct ohms for Vibration Motor circuit?

winneymj, 2019-07-21:
Hi,
I am a avid maker and looked at your watch with interest as I have been trying to make something like this for a while.  Anyhow I have built a small vibration motor board for bread boarding based on your design but had problems with the motor not turning.  I think I eventually tracked it down to the fact the motor has internal resistance of approx 24 Ohms and if put in series with a 330 Ohm resistor as detailed in your schematic, you have created a voltage divider that only gives the motor 223 mV, nowhere near enough current to vibrate.  Am I reading the schematic incorrectly?
Please be kind as I am not an electrical engineer and I fully understand if this was my mistake.
Thanks
Mark

winneymj, 2019-07-30:
Figured it out

Closed 2019-07-30.

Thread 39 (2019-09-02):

Missing parts

ItsJust-Wright, 2019-09-02:
I was populating the PCB and after referencing the completed PCB image on github I found that I was missing "L2", "R14" and the pin set that the LCD screen snaps into. These also aren't on the Bill of sale which leads me to believe I may just be missing something. If someone could please provide the part numbers that would be much appreciated.

dannygrob, 2019-09-02:
**Connector** was mentioned here, the BOM should be updated indeed:
https://github.com/S-March/smarchWatch_PUBLIC/issues/5

**L2** was mentioned here:
https://github.com/S-March/smarchWatch_PUBLIC/issues/29

**R14** is 0-ohm according to the schematic

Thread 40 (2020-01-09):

I've created an alternative version based on SmarchWatch

dannygrob, 2020-01-09:
Hi

I've created a new version of the watch, but with touchscreen. I've also changed the housing to be printed on my resin printer for a nice look. I noticed that this project is missing a lot to actually make it work (it has the basic BLE and some display routines, but even backlight code is missing).

My version implements the display code a bit faster, adds touch support and has the code for the LIS3DH i2c chip. Also created time display and a menu. I struggled a lot, maybe we can help each other a bit more since a lot of people are interested in this watch. It is far from finished too, I mainly have a lot of issues debugging it. The tasks seem to stop, and I can't get the accelerometer and touch working at the same time. Also a real RTC is missing, and the sleep is broken atm. But take a look!

I'm working on changing the altium files to add the touch connector and fix some issues this one has (for ex. missing vref for debug and the vibrate motor 330ohm is not needed or it won't work)

https://github.com/dannygrob/OpenWatch

Danny

vanbluca, 2020-01-09:
This is awesome! Can’t wait to see more results!

d3mon187, 2020-01-24:
Hey @dannygrob , great to see someone else working on this project.  I'm a programmer that likes to get into things over his head, and this seems perfect.  I've got all the materials for the original project, so right now I'm working on figuring out how to solder everything and currently trying to figure out where everything goes.  Saw that you at least attempted to convert the pcb files to kicad, but couldn't figure out if you succeeded.  I think I went through the same steps as you, but once the project was in kicad it just threw errors on everything.  Did you manage to get it working, or did you switch to Altium?  I'm hoping to get away with something free, at least until I get my feet wet.  Altium lists upconvert as a website for hobbyists, but it doesn't seem to work for importing Altium either.

dannygrob, 2020-02-01:
I have a friend who had Altium, he just opened it there and modified the pcb. I think the original was Kicad though

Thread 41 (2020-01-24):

Wrong Ohm listed on Schematic or BOM

d3mon187, 2020-01-24:
Loaded up the atrium files in attrium reader, and noticed that it states R12 as being 0.39ohm.  The BOM sheet also says 0.39ohm but the digikey part number is for a 390ohm resister.  Is the part number incorrect, or is the schematic wrong?  Is there one of the other resistors that will work in it's place?  I've already laid everything out on the pcb, so it would be quite a pain to wait at this point.

Also, you people are insane neurosurgeons!  It will be an absolute miracle if I manage to get these specs of dust soldered to the board successfully.  LOL

Thanks!

S-March, 2020-01-25:
It should be 0.39 Ohm, it looks like that was an error in the output to the digikey part number. Unfortunately it needs to be that small one to do the battery life measurements. Good luck!

d3mon187, 2020-01-25:
Thanks, would this be the correct part to update the BOM list?  - https://www.digikey.com/product-detail/en/yageo/RL0805FR-070R39L/311-.39SCT-ND/1037225

I think I'll try and solder everything in place and just add this one when it comes in.  Otherwise I'm sure I'll loose a part.  Will probably order extras too just in case.  I really didn't grasp how small some of this stuff is from the pictures and already lost a capacitor that I dropped and then completely vanished.

Closed 2020-01-25.

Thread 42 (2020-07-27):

Board Parameters for Charger?

s-sandhu2000, 2020-07-27:
Hi there,

I was working on building Samson March's amazing smartwatch design but noticed that there were some missing details about the board parameters. The main PCB for the watch is fine, all the details are there. The charger, however, does not include the board parameters (ex: thickness, min. hole size, etc.).

I'm completely new to Altium/PCB design, so I'm still not completely sure how to figure out the parameters on my own. I can do some deductions based on what I have learned already, but I want to be completely sure so I don't make any mistakes.

d3mon187, 2020-07-27:
Hi,

First off, be sure to switch over to dannygrob's Openwatch project that was based off Smarch watch.  As it is right now on github, the smarchwatch is not functional, working, or near complete.

If you're wanting to source the pcb, I had some decent luck with jlpcb.com.  I think the pcb specs are in a pdf document on this project or Openwatch's.  I wouldn't worry too much about the charger at this point, as the project isn't really at a point where it's usable on a day to day basis.  I've had mine hardwired to the programmer and some usb power leads for a while.  I plan to work on ota update capability next, but have a big work project to finish first and I know Danny has been busy as well.  Once ota is working I think it'll be a lot more practical.  At this point though, I want to say that this project is not cheap to get running or for the faint of heart, but it is a fantastic project for programmers who want to play with making hardware and SoC coding.

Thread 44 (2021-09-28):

Trying to Figure out the Antenna

YudiNz, 2021-09-28:
Hi, I am trying to see how the antenna works in this situation. I looked through the BOM but couldn't find it.

Looking at the schematics and PCB layout it seems like there is a Pi Network with a trace going to a via at the edge of the board. Is that trace the antenna? is it a 50ohm impedance trace connecting to ground via a via?

Could someone please help me understand this?

Edit: I see issue #39 and issue #35 but now I am trying to understand why the pi network was not needed? does the trace to the via have the required 50ohm impedance? also I understand that the a reason for using 31.25mm is because that's the quarter wavelength or closed to it for the 2.4GHz range

YudiNz, 2021-10-04:
Great video regarding the project via an interview by Robert Feranec regarding this. Antenna component is explained here. @45:15 link: [https://youtu.be/pKD4kBWA5cw?t=2715](url)

Leaving it here for the future if other people are interested in it too.

Closed 2021-10-04.

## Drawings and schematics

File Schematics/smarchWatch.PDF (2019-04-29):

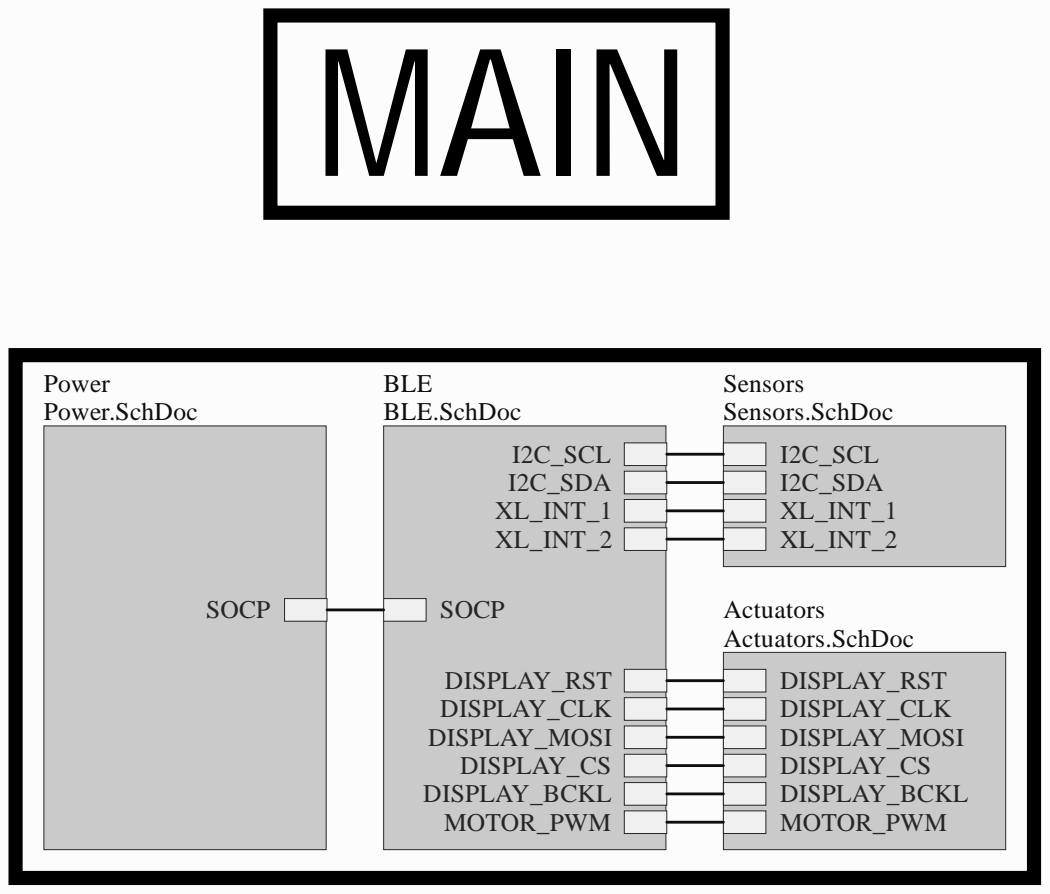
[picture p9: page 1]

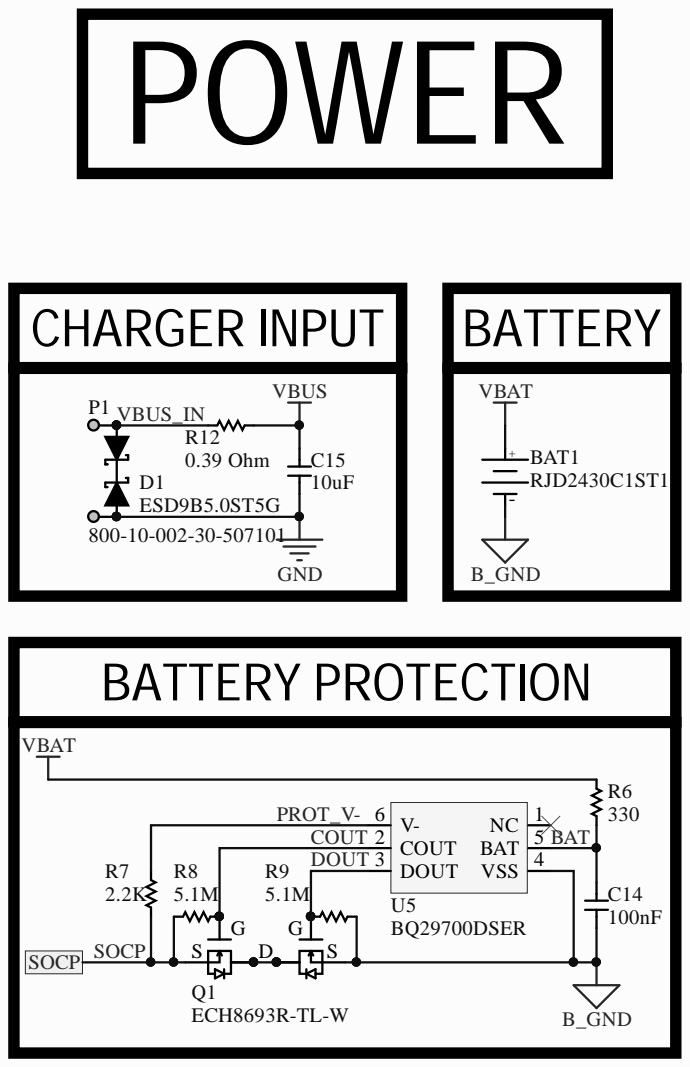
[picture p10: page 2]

DOUT
5.1M

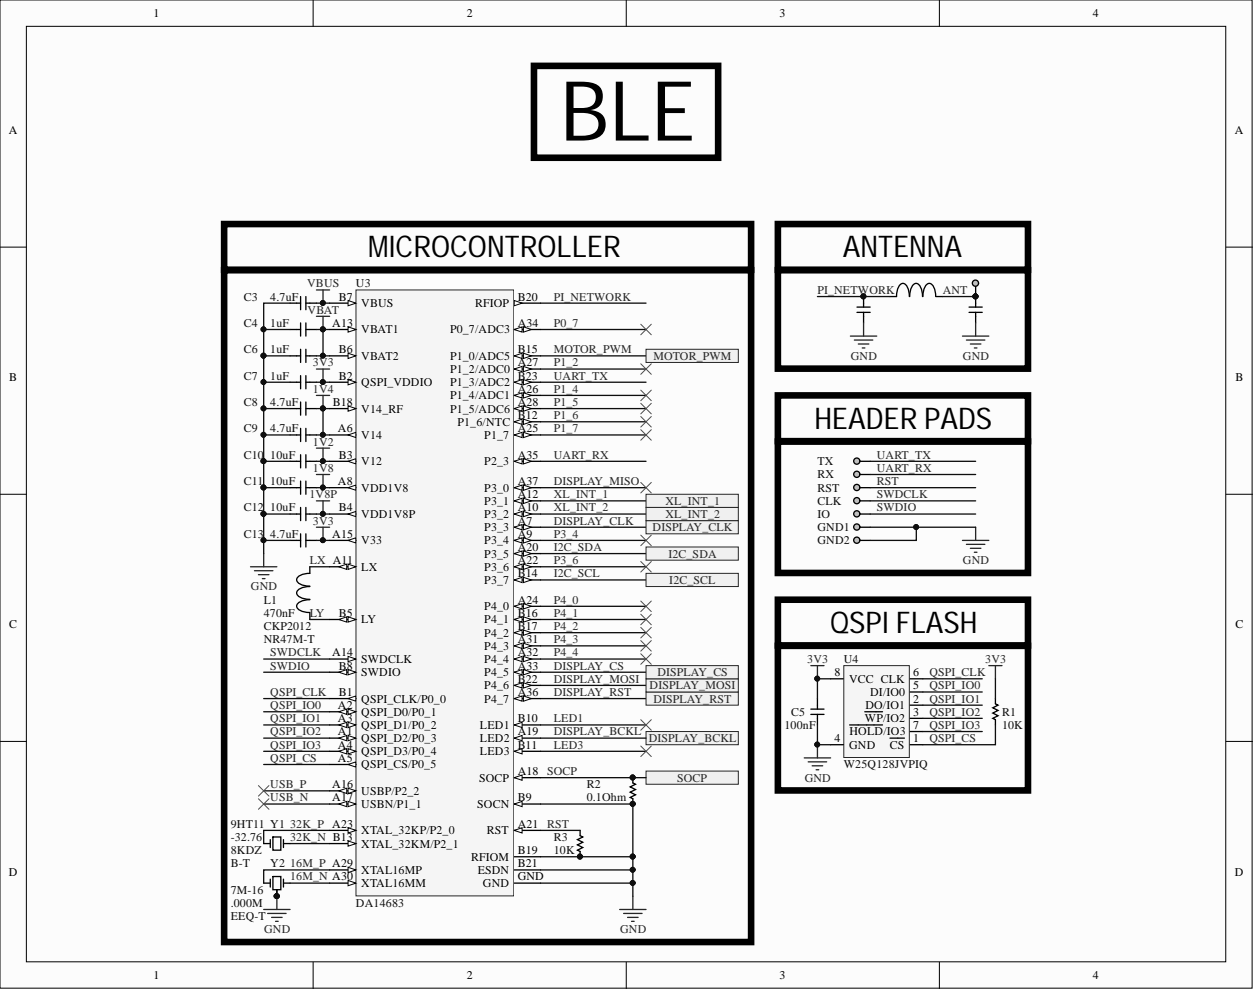
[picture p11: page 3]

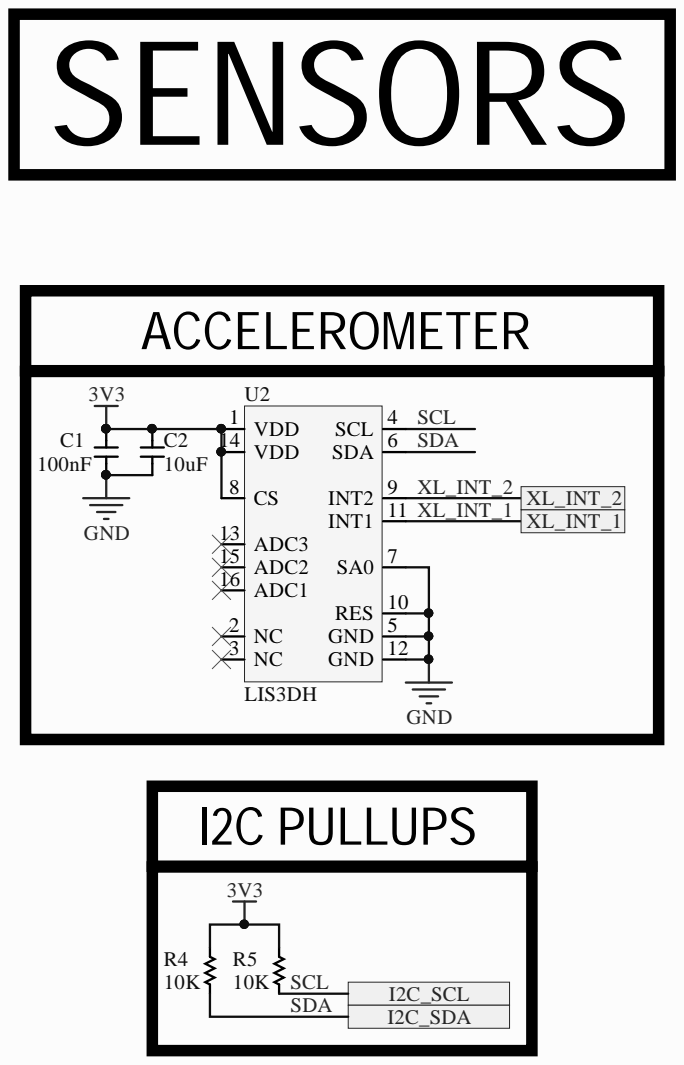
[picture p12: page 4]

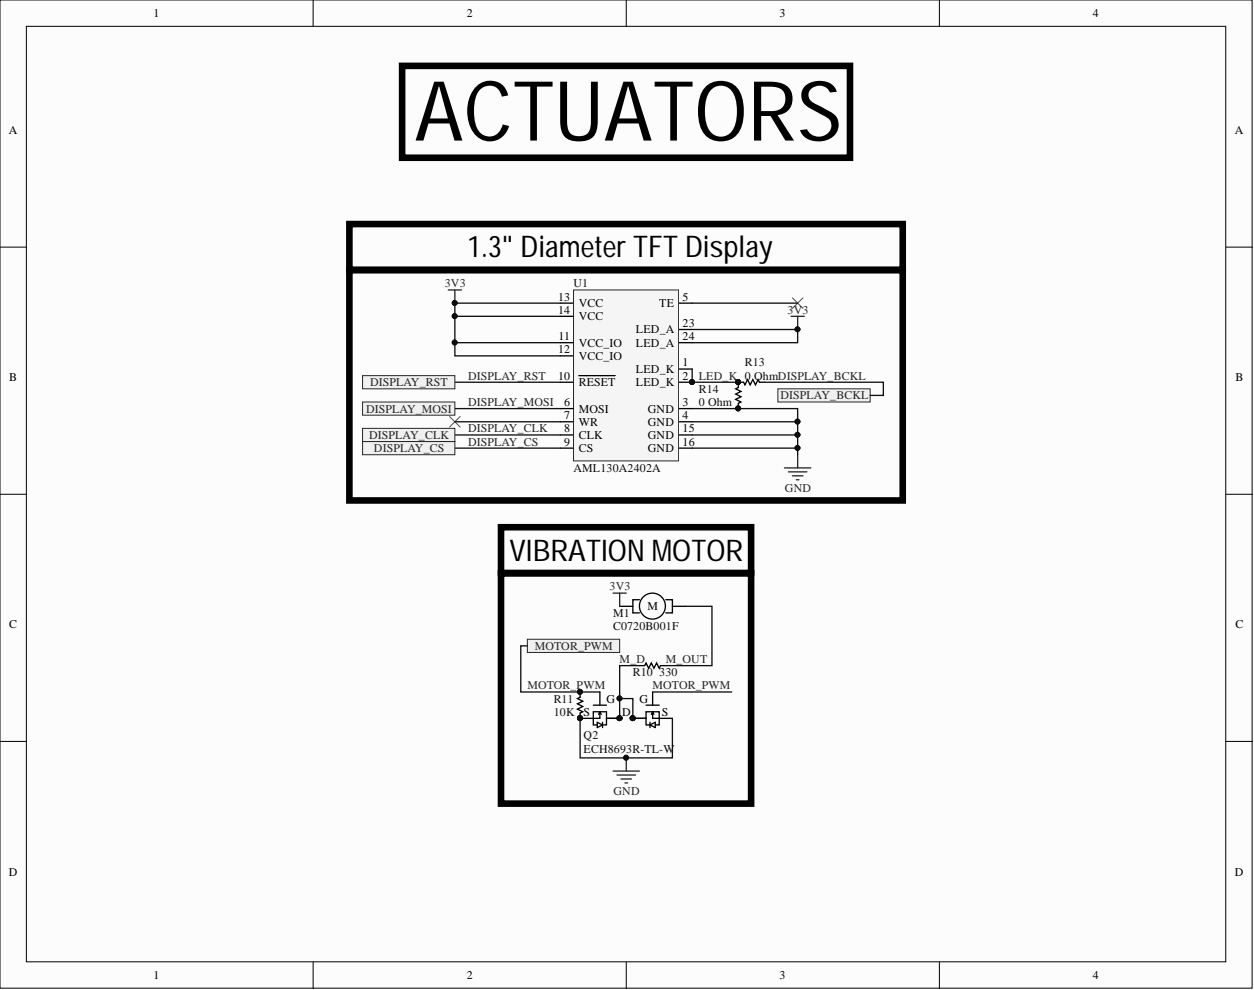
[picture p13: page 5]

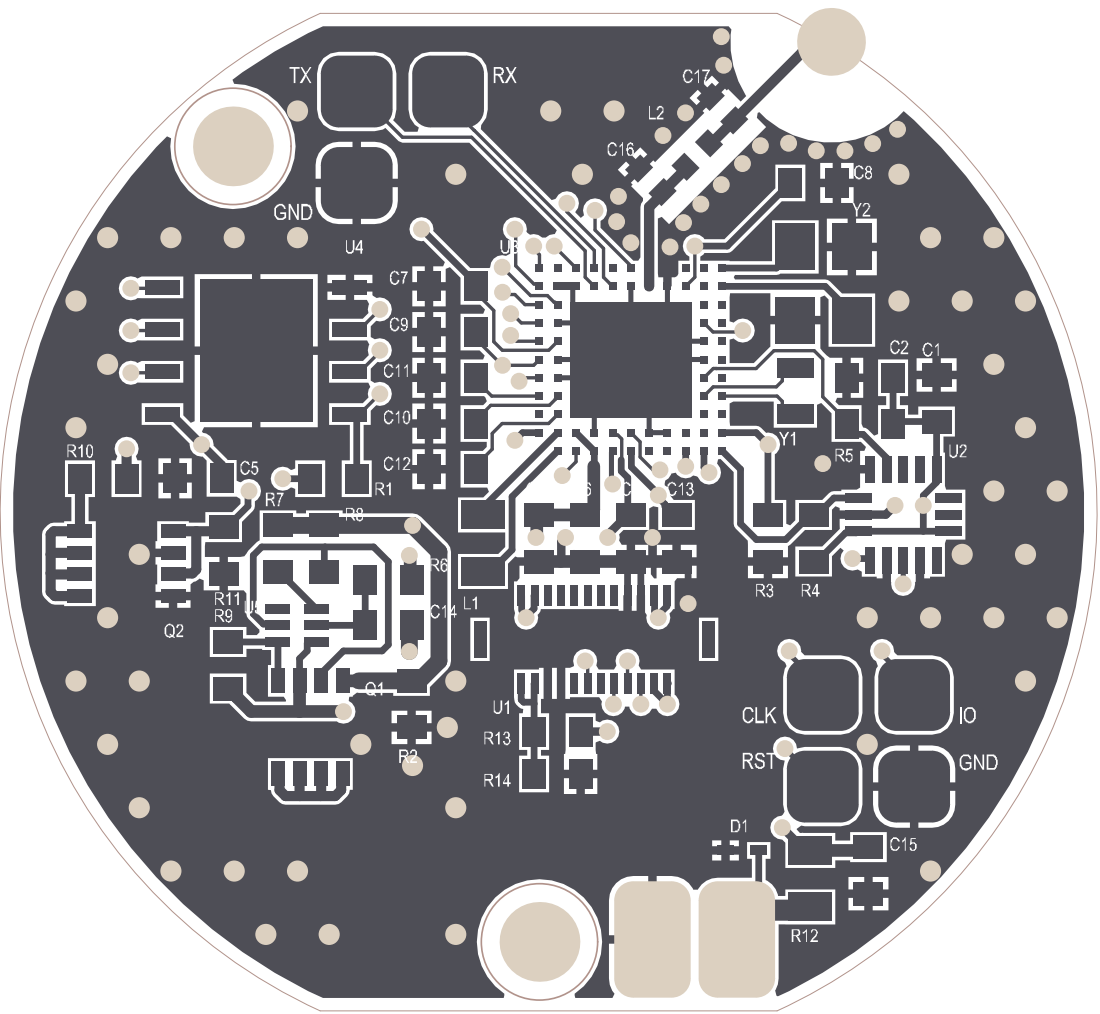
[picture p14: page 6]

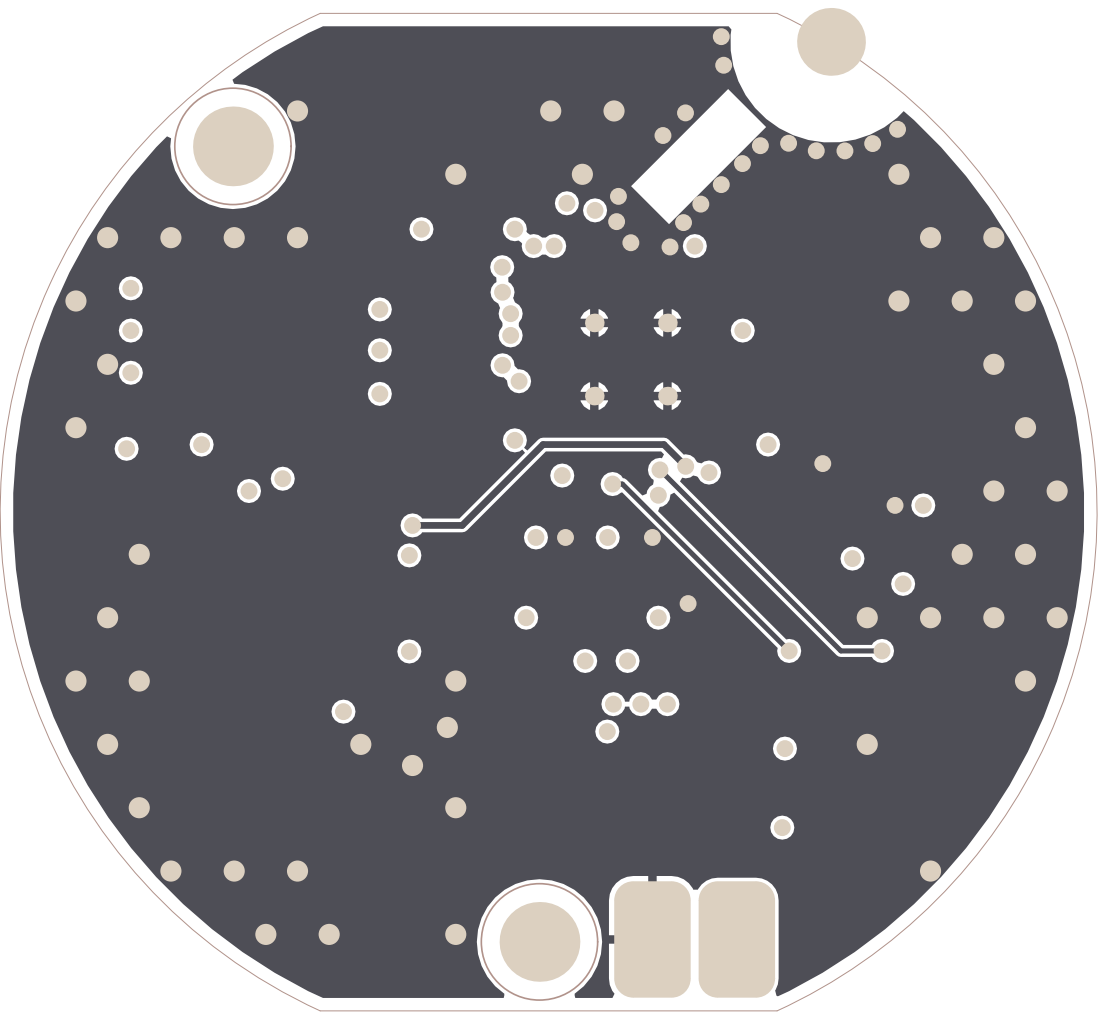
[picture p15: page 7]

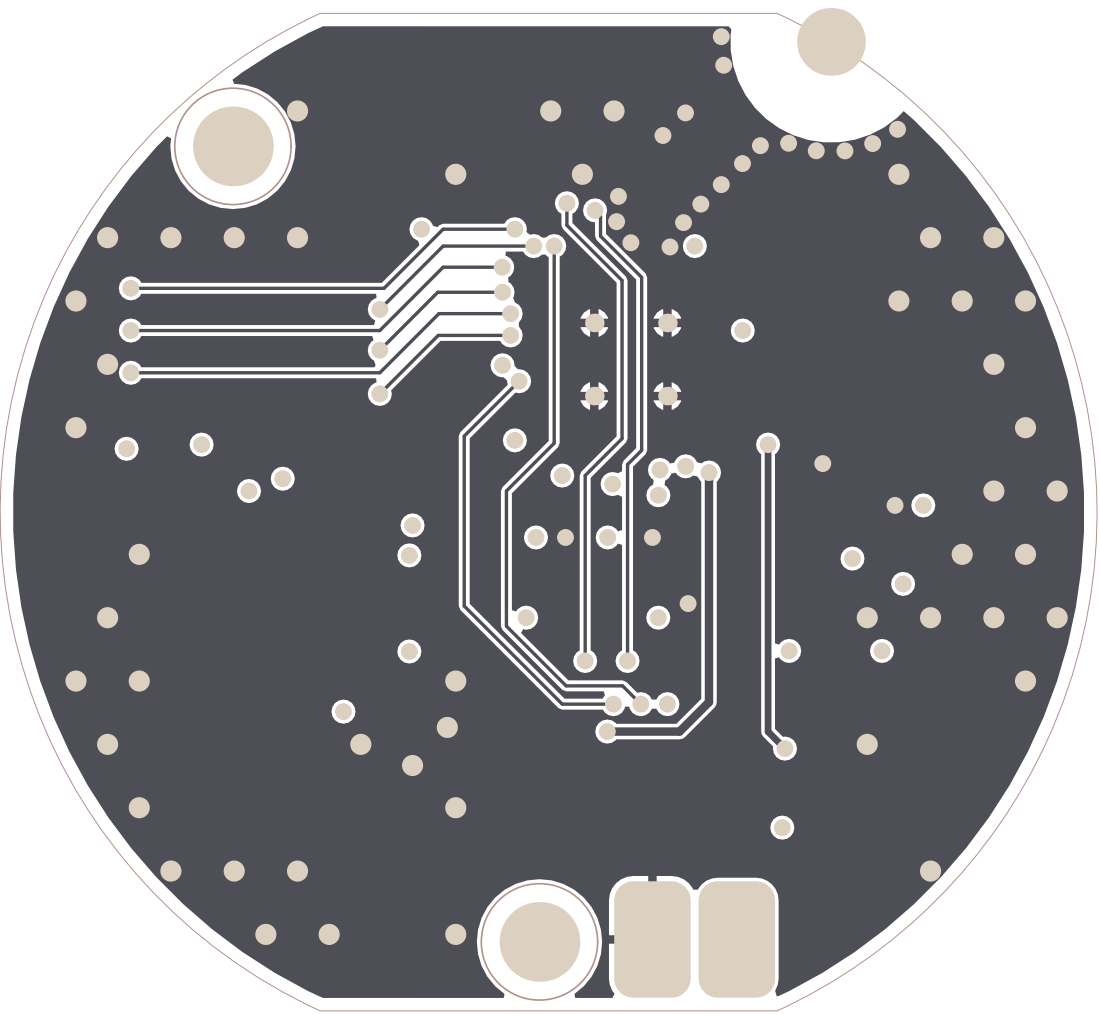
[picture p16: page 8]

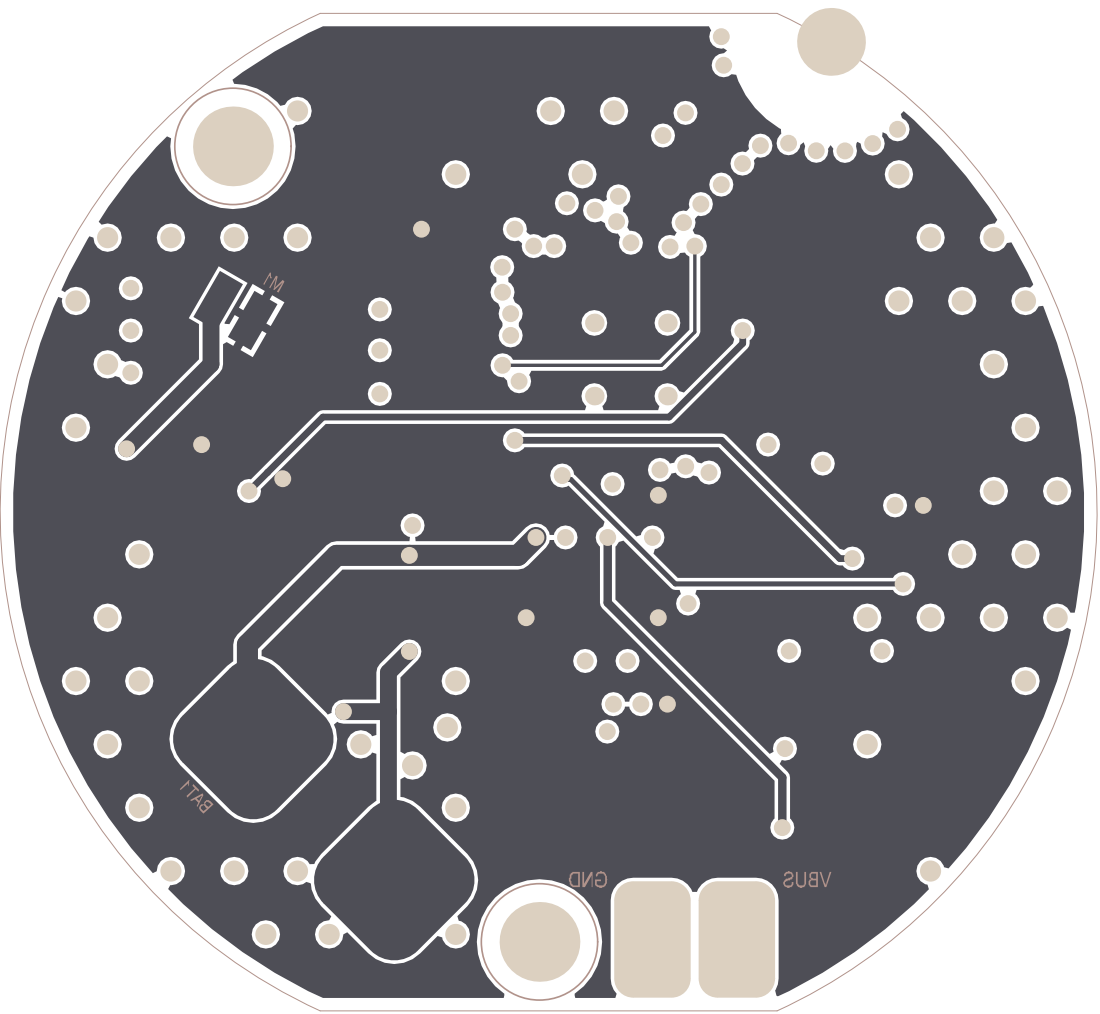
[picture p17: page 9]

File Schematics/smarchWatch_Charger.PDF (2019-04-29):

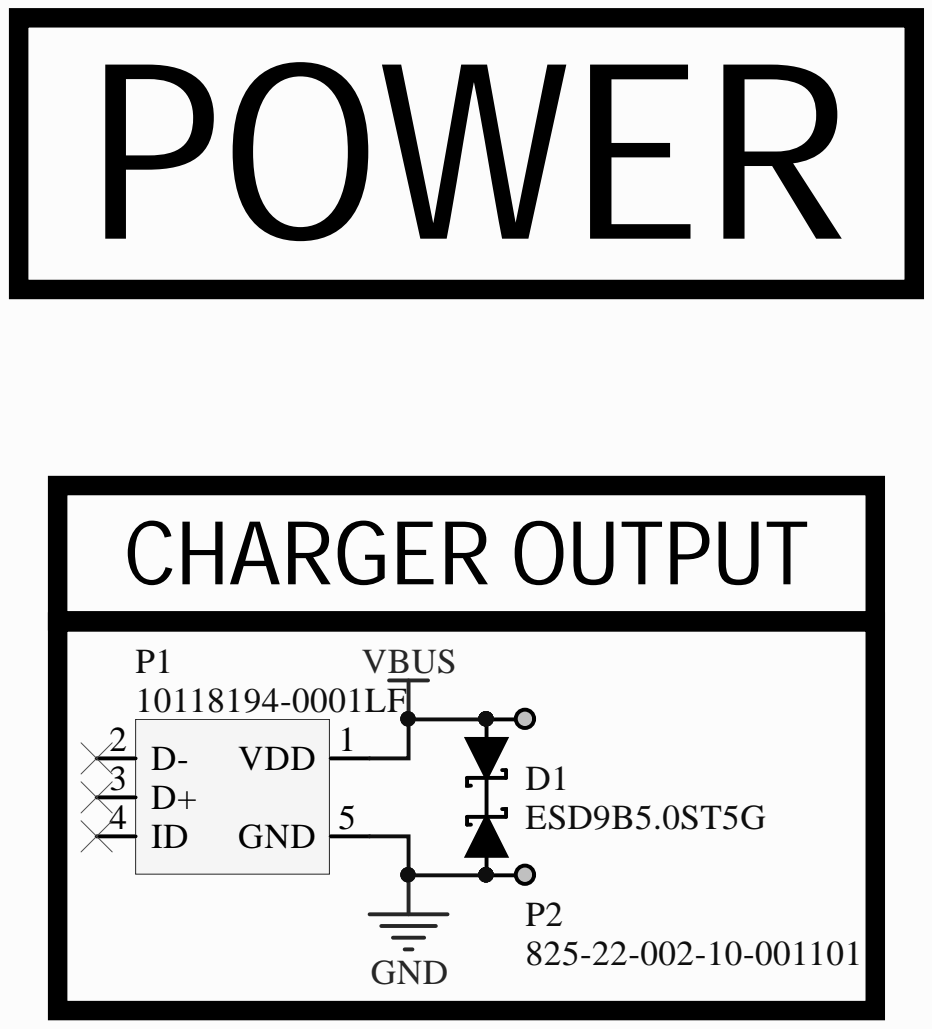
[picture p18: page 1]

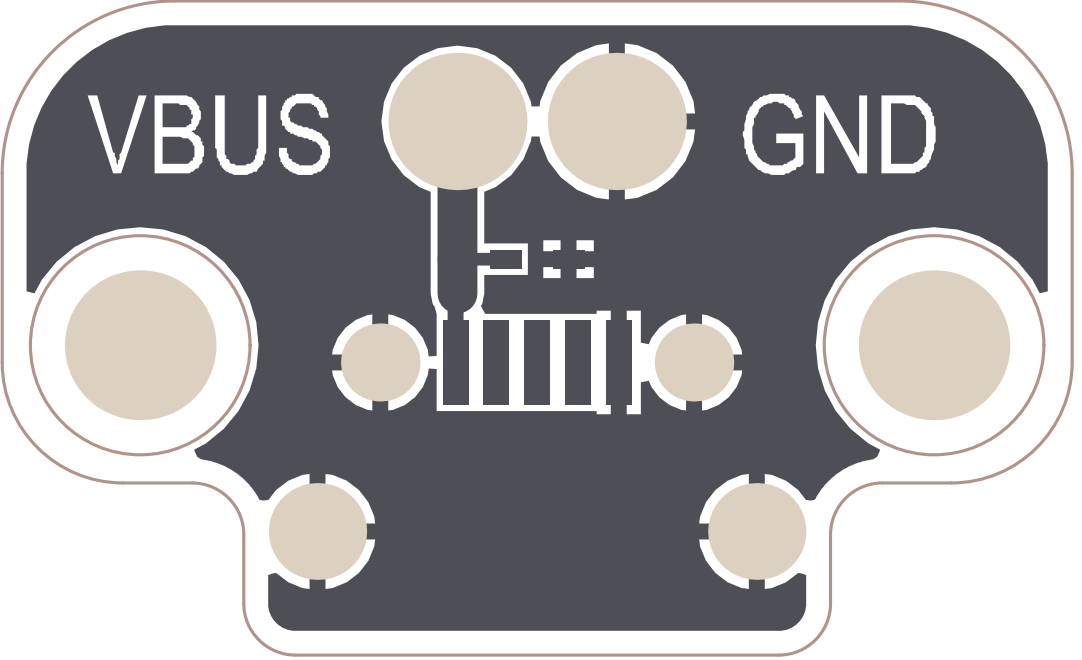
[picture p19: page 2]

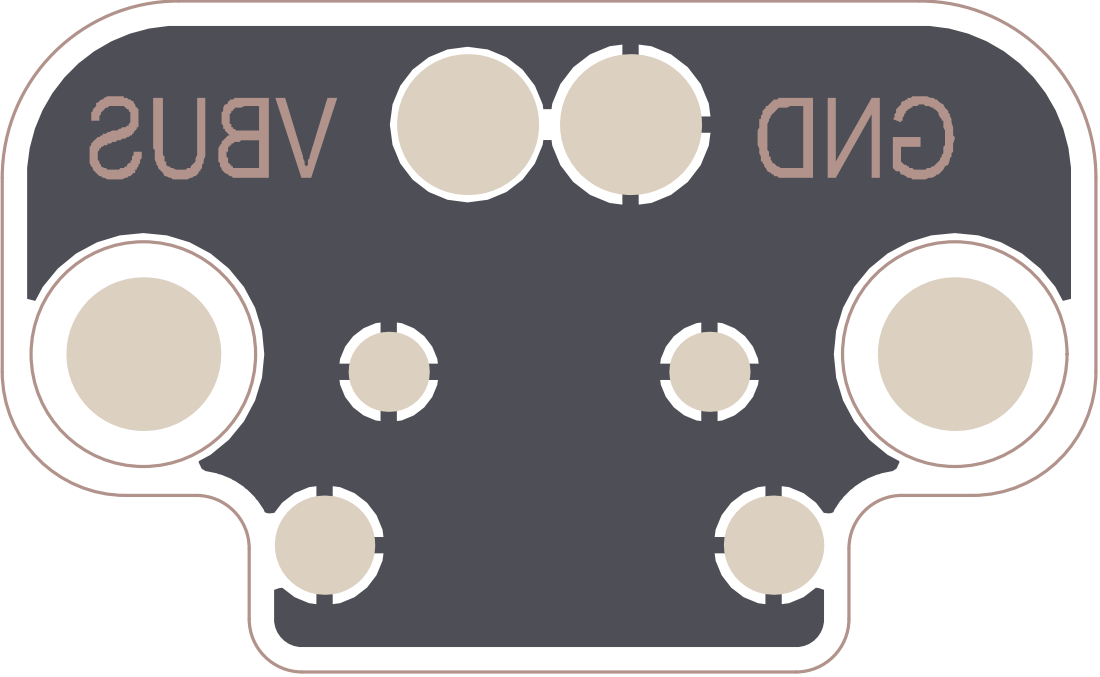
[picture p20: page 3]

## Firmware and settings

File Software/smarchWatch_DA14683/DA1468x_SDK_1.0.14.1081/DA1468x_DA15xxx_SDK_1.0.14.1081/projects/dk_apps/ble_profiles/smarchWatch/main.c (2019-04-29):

/**
 ****************************************************************************************
 *
 * @file main.c
 *
 * @brief ANCS application
 *
 * Copyright (C) 2015-2018 Dialog Semiconductor.
 * This computer program includes Confidential, Proprietary Information
 * of Dialog Semiconductor. All Rights Reserved.
 *
 ****************************************************************************************
 */
/* Standard includes. */
#include <string.h>
#include <stdbool.h>

#include "osal.h"
#include "resmgmt.h"
#include "ad_ble.h"
#include "ad_spi.h"
#include "ad_nvms.h"
#include "ble_mgr.h"
#include "hw_gpio.h"
#include "hw_wkup.h"
#include "sys_clock_mgr.h"
#include "sys_power_mgr.h"
#include "sys_watchdog.h"
#include "ancs_config.h"
#include "platform_devices.h"

/* Task priorities */
#define mainBLE_ANCS_TASK_PRIORITY              ( OS_TASK_PRIORITY_NORMAL )
#define mainDISPLAY_TASK_PRIORITY               ( OS_TASK_PRIORITY_NORMAL )
#define mainFLASH_TASK_PRIORITY                 ( OS_TASK_PRIORITY_NORMAL )

#if dg_configUSE_WDOG
INITIALISED_PRIVILEGED_DATA int8_t idle_task_wdog_id = -1;
#endif

/*
 * Perform any application specific hardware configuration.  The clocks,
 * memory, etc. are configured before main() is called.
 */
static void prvSetupHardware( void );
/*
 * Task functions .
 */
#if LOAD_NEW_IMAGES
        void storeInFlash_task(void *params);
#else
        void ancs_task(void *params);
        void display_task(void *params);
#endif

static OS_TASK handle;

/*
 * Wakeup handler
 */
void ancs_client_wkup_handler(void);

static void wkup_handler()
{
#if dg_configBLACK_ORCA_IC_REV == BLACK_ORCA_IC_REV_A
        hw_wkup_reset_counter();
#endif
        hw_wkup_reset_interrupt();

        ancs_client_wkup_handler();
}

static void init_wakeup(void)
{
        hw_wkup_init(NULL);
        hw_wkup_configure_pin(CFG_TRIGGER_PERFORM_NOTIF_ACTION_GPIO_PORT,
                                                        CFG_TRIGGER_PERFORM_NOTIF_ACTION_GPIO_PIN, 1,
                                                        HW_WKUP_PIN_STATE_LOW);
#if dg_configBLACK_ORCA_IC_REV == BLACK_ORCA_IC_REV_A
        hw_wkup_set_counter_threshold(1);
#endif
        hw_wkup_set_debounce_time(10);

        hw_wkup_register_interrupt(wkup_handler, 1);
}

/**
 * @brief System Initialization and creation of the BLE task
 */
static void system_init( void *pvParameters )
{
#if defined CONFIG_RETARGET
        extern void retarget_init(void);
#endif

        /* Prepare clocks. Note: cm_cpu_clk_set() and cm_sys_clk_set() can be called only from a
         * task since they will suspend the task until the XTAL16M has settled and, maybe, the PLL
         * is locked.
         */
        cm_sys_clk_init(sysclk_XTAL16M);
//        cm_sys_clk_init(sysclk_PLL96);
        cm_apb_set_clock_divider(apb_div1);
        cm_ahb_set_clock_divider(ahb_div1);
        cm_lp_clk_init();

        /*
         * Initialize platform watchdog
         */
        sys_watchdog_init();

#if dg_configUSE_WDOG
        // Register the Idle task first.
        idle_task_wdog_id = sys_watchdog_register(false);
        ASSERT_WARNING(idle_task_wdog_id != -1);
        sys_watchdog_configure_idle_id(idle_task_wdog_id);
#endif

        /* Set system clock */
//        cm_sys_clk_set(sysclk_XTAL16M);
        cm_sys_clk_set(sysclk_PLL96);

        /* Prepare the hardware to run this demo. */
        prvSetupHardware();

        /* init resources */
        resource_init();

#if defined CONFIG_RETARGET
        retarget_init();
#endif

        /* Initialize wakeup GPIO pins used in demo */
        init_wakeup();

        /* Set the desired sleep mode. */
        pm_set_wakeup_mode(true);

        #if LOAD_NEW_IMAGES
                pm_set_sleep_mode(pm_mode_active);
                /* Start the Flash Storage application task. */
                OS_TASK_CREATE("Flash Storage Task",                     /* The text name assigned to the task, for
                                                                      debug only; not used by the kernel. */
                               storeInFlash_task,                          /* The function that implements the task. */
                               NULL,                               /* The parameter passed to the task. */
                               4096,                               /* The number of bytes to allocate to the
                                                                      stack of the task. */
                               mainFLASH_TASK_PRIORITY,         /* The priority assigned to the task. */
                               handle);                            /* The task handle. */
                OS_ASSERT(handle);
        #else
                pm_set_sleep_mode(pm_mode_extended_sleep);
                /* Initialize BLE Manager */
                ble_mgr_init();

                /* Start the Display application task. */
                OS_TASK_CREATE("Display Task",                     /* The text name assigned to the task, for
                                                                      debug only; not used by the kernel. */
                               display_task,                          /* The function that implements the task. */
                               NULL,                               /* The parameter passed to the task. */
                               4096,                               /* The number of bytes to allocate to the
                                                                      stack of the task. */
                               mainDISPLAY_TASK_PRIORITY,         /* The priority assigned to the task. */
                               handle);                            /* The task handle. */
                OS_ASSERT(handle);

                /* Start the ANCS Profile application task. */
                OS_TASK_CREATE("ANCS Profile",                     /* The text name assigned to the task, for
                                                                      debug only; not used by the kernel. */
                               ancs_task,                          /* The function that implements the task. */
                               NULL,                               /* The parameter passed to the task. */
                               1024,                               /* The number of bytes to allocate to the
                                                                      stack of the task. */
                               mainBLE_ANCS_TASK_PRIORITY,         /* The priority assigned to the task. */
                               handle);                            /* The task handle. */
                OS_ASSERT(handle);
        #endif


        /* the work of the SysInit task is done */
        OS_TASK_DELETE(OS_GET_CURRENT_TASK());
}
/*-----------------------------------------------------------*/

/**
 * @brief Basic initialization and creation of the system initialization task.
 */
int main( void )
{
        OS_BASE_TYPE status;
        cm_clk_init_low_level();                            /* Basic clock initializations. */

        /* Start SysInit task. */
        status = OS_TASK_CREATE("SysInit",                /* The text name assigned to the task, for
                                                             debug only; not used by the kernel. */
                                system_init,              /* The System Initialization task. */
                                ( void * ) 0,             /* The parameter passed to the task. */
                                1024,                     /* The number of bytes to allocate to the
                                                             stack of the task. */
                                OS_TASK_PRIORITY_HIGHEST, /* The priority assigned to the task. */
                                handle );                 /* The task handle */
        OS_ASSERT(status == OS_TASK_CREATE_SUCCESS);

        /* Start the tasks and timer running. */
        vTaskStartScheduler();

        /* If all is well, the scheduler will now be running, and the following
        line will never be reached.  If the following line does execute, then
        there was insufficient FreeRTOS heap memory available for the idle and/or
        timer tasks     to be created.  See the memory management section on the
        FreeRTOS web site for more details. */
        for( ;; );
}

/**
 * \brief Initialize the peripherals domain after power-up.
 *
 */
static void periph_init(void)
{
        //UART
        hw_gpio_set_pin_function(HW_GPIO_PORT_1, HW_GPIO_PIN_3, HW_GPIO_MODE_OUTPUT,
                HW_GPIO_FUNC_UART2_TX);
        hw_gpio_set_pin_function(HW_GPIO_PORT_2, HW_GPIO_PIN_3, HW_GPIO_MODE_OUTPUT,
                HW_GPIO_FUNC_UART2_RX);

        //SPI
        hw_gpio_set_pin_function(HW_GPIO_PORT_3, HW_GPIO_PIN_3, HW_GPIO_MODE_OUTPUT,
                HW_GPIO_FUNC_SPI_CLK);
        hw_gpio_set_pin_function(HW_GPIO_PORT_3, HW_GPIO_PIN_0, HW_GPIO_MODE_INPUT,
                HW_GPIO_FUNC_SPI_DI);
        hw_gpio_set_pin_function(HW_GPIO_PORT_4, HW_GPIO_PIN_6, HW_GPIO_MODE_OUTPUT,
                HW_GPIO_FUNC_SPI_DO);
        hw_gpio_set_pin_function(HW_GPIO_PORT_4, HW_GPIO_PIN_5, HW_GPIO_MODE_OUTPUT,
                HW_GPIO_FUNC_SPI_EN);
        hw_gpio_set_active(HW_GPIO_PORT_4,HW_GPIO_PIN_5);

        //Display Reset
        hw_gpio_set_pin_function(HW_GPIO_PORT_4, HW_GPIO_PIN_7, HW_GPIO_MODE_OUTPUT,
                HW_GPIO_FUNC_GPIO);
        hw_gpio_set_active(HW_GPIO_PORT_4,HW_GPIO_PIN_7);

        //BLE TURN DOWN CALL
        hw_gpio_configure_pin(CFG_TRIGGER_PERFORM_NOTIF_ACTION_GPIO_PORT,
                        CFG_TRIGGER_PERFORM_NOTIF_ACTION_GPIO_PIN, HW_GPIO_MODE_INPUT_PULLUP,
                        HW_GPIO_FUNC_GPIO, 1);
}

static void prvSetupHardware( void )
{
        /* Init hardware */
        pm_system_init(periph_init);
}

/**
 * @brief Malloc fail hook
 */
void vApplicationMallocFailedHook( void )
{
        /* vApplicationMallocFailedHook() will only be called if
	configUSE_MALLOC_FAILED_HOOK is set to 1 in FreeRTOSConfig.h.  It is a hook
	function that will get called if a call to pvPortMalloc() fails.
	pvPortMalloc() is called internally by the kernel whenever a task, queue,
	timer or semaphore is created.  It is also called by various parts of the
	demo application.  If heap_1.c or heap_2.c are used, then the size of the
	heap available to pvPortMalloc() is defined by configTOTAL_HEAP_SIZE in
	FreeRTOSConfig.h, and the xPortGetFreeHeapSize() API function can be used
	to query the size of free heap space that remains (although it does not
	provide information on how the remaining heap might be fragmented). */
        taskDISABLE_INTERRUPTS();
        for( ;; );
}

/**
 * @brief Application idle task hook
 */
void vApplicationIdleHook( void )
{
        /* vApplicationIdleHook() will only be called if configUSE_IDLE_HOOK is set
           to 1 in FreeRTOSConfig.h.  It will be called on each iteration of the idle
           task. It is essential that code added to this hook function never attempts
           to block in any way (for example, call xQueueReceive() with a block time
           specified, or call vTaskDelay()).  If the application makes use of the
           vTaskDelete() API function (as this demo application does) then it is also
           important that vApplicationIdleHook() is permitted to return to its calling
           function, because it is the responsibility of the idle task to clean up
           memory allocated by the kernel to any task that has since been deleted. */

#if dg_configUSE_WDOG
        sys_watchdog_notify(idle_task_wdog_id);
#endif
}

/**
 * @brief Application stack overflow hook
 */
void vApplicationStackOverflowHook( OS_TASK pxTask, char *pcTaskName )
{
        ( void ) pcTaskName;
        ( void ) pxTask;

        /* Run time stack overflow checking is performed if
	configCHECK_FOR_STACK_OVERFLOW is defined to 1 or 2.  This hook
	function is called if a stack overflow is detected. */
        taskDISABLE_INTERRUPTS();
        for( ;; );
}

/**
 * @brief Application tick hook
 */
void vApplicationTickHook( void )
{

        OS_POISON_AREA_CHECK( OS_POISON_ON_ERROR_HALT, result );

}

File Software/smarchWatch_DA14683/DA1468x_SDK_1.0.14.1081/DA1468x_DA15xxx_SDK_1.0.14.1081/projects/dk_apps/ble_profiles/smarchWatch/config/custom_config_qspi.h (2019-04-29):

/**
\addtogroup BSP
\{
\addtogroup CONFIG
\{
\addtogroup CUSTOM
\{
*/

/**
 ****************************************************************************************
 *
 * @file custom_config_qspi.h
 *
 * @brief Board Support Package. User Configuration file for cached QSPI mode.
 *
 * Copyright (C) 2015-2017 Dialog Semiconductor.
 * This computer program includes Confidential, Proprietary Information
 * of Dialog Semiconductor. All Rights Reserved.
 *
 ****************************************************************************************
 */

#ifndef CUSTOM_CONFIG_QSPI_H_
#define CUSTOM_CONFIG_QSPI_H_

#include "bsp_definitions.h"

#define CONFIG_USE_BLE
#undef CONFIG_USE_FTDF

#define CONFIG_BLE_STORAGE (1)

#define CONFIG_RETARGET
#define CONFIG_RETARGET_UART    HW_UART2


#define dg_configTESTMODE_MEASURE_SLEEP_CURRENT (0)

#define dg_configUSE_LP_CLK                     LP_CLK_32768
#define dg_configEXEC_MODE                      MODE_IS_CACHED
#define dg_configCODE_LOCATION                  NON_VOLATILE_IS_FLASH
#define dg_configEXT_CRYSTAL_FREQ               EXT_CRYSTAL_IS_16M

#define dg_configIMAGE_SETUP                    DEVELOPMENT_MODE
#define dg_configEMULATE_OTP_COPY               (0)

#define dg_configUSER_CAN_USE_TIMER1            (0)

#define dg_configUSE_WDOG                       (1)


#define dg_configFLASH_CONNECTED_TO             (FLASH_CONNECTED_TO_1V8)
#define dg_configFLASH_POWER_DOWN               (0)

#define dg_configPOWER_1V8_ACTIVE               (1)
#define dg_configPOWER_1V8_SLEEP                (1)

#define dg_configBATTERY_TYPE                   (BATTERY_TYPE_LIMN2O4)
#define dg_configBATTERY_CHARGE_CURRENT         2       // 30mA
#define dg_configBATTERY_PRECHARGE_CURRENT      20      // 2.1mA
#define dg_configBATTERY_CHARGE_NTC             1       // disabled

#define dg_configUSE_USB                        0
#define dg_configUSE_USB_CHARGER                0
#define dg_configALLOW_CHARGING_NOT_ENUM        1

#define dg_configUSE_ProDK                      (1)

#define dg_configUSE_SW_CURSOR                  (1)

#define dg_configCACHEABLE_QSPI_AREA_LEN        0x80000//(NVMS_PARAM_PART_start - MEMORY_QSPIF_BASE)
#define dg_configQSPI_CODE_SIZE                 (256 * 1024)

/*************************************************************************************************\
 * Custom flash specific config
 */
#define dg_configFLASH_HEADER_FILE              "qspi_w25q128.h"
#define dg_configFLASH_DEVICE_TYPE              W25Q128
#define dg_configFLASH_DENSITY                  W25Q_128Mb_SIZE
#define USE_PARTITION_TABLE_16MB


/*************************************************************************************************\
 * Memory layout specific config
 */
#define dg_configQSPI_CACHED_RAM_SIZE           ( 56 * 1024)
#define dg_configQSPI_CACHED_RETRAM_0_SIZE      ( 72 * 1024)//72*1024

/*************************************************************************************************\
 * FreeRTOS specific config
 */
#define OS_FREERTOS                              /* Define this to use FreeRTOS */
#define configTOTAL_HEAP_SIZE                    (19 * 1024)//19*1024//19456   /* This is the FreeRTOS Total Heap Size */

/*************************************************************************************************\
 * Peripheral specific config
 */
#define dg_configFLASH_ADAPTER                  1
#define dg_configNVMS_ADAPTER                   1
#define dg_configNVMS_VES                       1
#define dg_configDISABLE_BACKGROUND_FLASH_OPS   1
#define dg_configGPADC_ADAPTER                  1

/*************************************************************************************************\
 * BLE device config
 */
#define dg_configBLE_CENTRAL                    (0)
#define dg_configBLE_GATT_SERVER                (0)
#define dg_configBLE_OBSERVER                   (0)
#define dg_configBLE_BROADCASTER                (0)
#define dg_configBLE_L2CAP_COC                  (0)

/**************************************************************************************************\
* Macros for enabling SPI operations using Adapters
*/
#define dg_configUSE_HW_SPI                     1
#define dg_configSPI_ADAPTER                    1
#define CONFIG_SPI_ONE_DEVICE_ON_BUS            1
#define CONFIG_SPI_EXCLUSIVE_OPEN               1
#define CONFIG_SPI_DISPLAY                      1

/**************************************************************************************************\
* Macros for enabling image loader into memory
*/
#define LOAD_NEW_IMAGES                         0
#if LOAD_NEW_IMAGES
#define dg_configUART_ADAPTER                   1
#else
#define dg_configUART_ADAPTER                   0
#endif


/* Include bsp default values */
#include "bsp_defaults.h"
/* Include memory layout */
#include "bsp_memory_layout.h"

#endif /* CUSTOM_CONFIG_QSPI_H_ */

/**
\}
\}
\}
*/

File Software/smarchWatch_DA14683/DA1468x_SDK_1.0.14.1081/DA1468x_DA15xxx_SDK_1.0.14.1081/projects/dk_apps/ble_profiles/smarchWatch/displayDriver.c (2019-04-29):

/*
 * displayDriver.c
 *
 *  Created on: Jan 15, 2019
 *      Author: samsonm
 */

#include <stdint.h>
#include "math.h"
#include "displayDriver.h"
#include "platform_devices.h"
#include "ad_spi.h"
#include "ad_nvms.h"
#include "miniDB.h"

int absoluteValue(int NUMBER)
{
    if(NUMBER<0)
    {
        return -NUMBER;
    }
    else
    {
        return NUMBER;
    }
}

void displayWriteCommand(int COMMAND)
{
        spi_device displaySpi = ad_spi_open(DISPLAY_SPI);
        hw_spi_set_9th_bit(ad_spi_get_hw_spi_id(displaySpi),0);
        ad_spi_write(displaySpi,(uint8_t *)&COMMAND,1);
        ad_spi_close(displaySpi);
}
void displayWriteData(int DATA)
{
        spi_device displaySpi = ad_spi_open(DISPLAY_SPI);
        hw_spi_set_9th_bit(ad_spi_get_hw_spi_id(displaySpi),1);
        ad_spi_write(displaySpi,(uint8_t *)&DATA,1);
        ad_spi_close(displaySpi);
}
void displayWriteDataBuf(uint8_t DATA[], int DATA_SIZE)
{
        spi_device displaySpi = ad_spi_open(DISPLAY_SPI);
        hw_spi_set_9th_bit(ad_spi_get_hw_spi_id(displaySpi),1);
        ad_spi_write(displaySpi,DATA,DATA_SIZE);
        ad_spi_close(displaySpi);
}
void displayInit(void)
{
        //Software Reset
        hw_gpio_set_inactive(HW_GPIO_PORT_4, HW_GPIO_PIN_7);
        OS_DELAY_MS(10);
        hw_gpio_set_active(HW_GPIO_PORT_4,HW_GPIO_PIN_7);
        OS_DELAY_MS(10);
        //Out of sleep mode
        displayWriteCommand(ST7789_SLPOUT);
        OS_DELAY_MS(10);
        //Set the color mode to 16-bit
        displayWriteCommand(ST7789_COLMOD);
        displayWriteData(0x55);
        OS_DELAY_MS(10);
        //Set the memory access control so that
        //display data comes as row address then
        //column address
        //Also sets refresh from bottom to top
        displayWriteCommand(ST7789_MADCTL);
        displayWriteData(0x00);
        //Column address start and end
        displaySetColumn(ST7789_XSTART,ST7789_WIDTH);
        //Row address start and end
        displaySetRow(ST7789_YSTART,ST7789_HEIGHT);
        //Enable extended command table
        displayWriteCommand(ST7789_CMD2EN);
        displayWriteData(0x5A);
        displayWriteData(0x69);
        displayWriteData(0x02);
        displayWriteData(0x01);
        //Set frame rate to 111 Hz (max)
        displayWriteCommand(ST7789_FRCTRL2);
        displayWriteData(0x01);
        //Set inversion on
        displayWriteCommand(ST7789_INVON);
        //Set normal display on
        displayWriteCommand(ST7789_NORON);
        OS_DELAY_MS(10);
        //Turn display on
        displayWriteCommand(ST7789_DISPON);
        OS_DELAY_MS(10);

        OS_DELAY_MS(1000); //TODO: CAN THIS BE REDUCED?
        ad_nvms_init();
}
void displaySetRotation(int ORIENTATION)
{
    displayWriteCommand(ST7789_MADCTL);
    switch(ORIENTATION)
    {
        case 0:
            displayWriteData(ST7789_MADCTL_MX | ST7789_MADCTL_MY | ST7789_MADCTL_RGB);
            break;
        case 1:
            displayWriteData(ST7789_MADCTL_MY | ST7789_MADCTL_MV | ST7789_MADCTL_RGB);
            break;
        case 2:
            displayWriteData(ST7789_MADCTL_RGB);
            break;
        case 3:
            displayWriteData(ST7789_MADCTL_MX | ST7789_MADCTL_MY | ST7789_MADCTL_RGB);
            break;
        default:
            displayWriteData(ST7789_MADCTL_MX | ST7789_MADCTL_MV | ST7789_MADCTL_RGB);
            break;
    }
}
void displaySetWindow(int XSTART, int XEND, int YSTART, int YEND)
{
    //Set column
    displaySetColumn(XSTART,XEND);
    //Set row
    displaySetRow(YSTART,YEND);
    //Begin writing frame to RAM
    displayWriteCommand(ST7789_RAMWR);
}
void displaySetWindow2(int XSTART, int XEND, int YSTART, int YEND)
{
    //Set column
    displaySetColumn(XSTART,XEND);
    //Set row
    displaySetRow(YSTART,YEND);
    //Begin writing frame to RAM
    displayWriteCommand(ST7789_RAMWR);
}
void displaySetColumn(int XSTART, int XEND)
{
    uint8_t xStartHigh = XSTART >> 8;
    uint8_t xStartLow = XSTART & 0xFF;
    uint8_t xEndHigh = XEND >> 8;
    uint8_t xEndLow = XEND & 0xFF;

    //Set window X dimensions
    displayWriteCommand(ST7789_CASET);
    displayWriteData(xStartHigh);
    displayWriteData(xStartLow);
    displayWriteData(xEndHigh);
    displayWriteData(xEndLow);
}
void displaySetRow(int YSTART, int YEND)
{
    //Add y-offset for display
    YSTART += ST7789_HEIGHT_OFFSET;
    YEND += ST7789_HEIGHT_OFFSET;

    uint8_t yStartHigh = (YSTART) >> 8;
    uint8_t yStartLow = (YSTART) & 0xFF;
    uint8_t yEndHigh = (YEND) >> 8;
    uint8_t yEndLow = (YEND) & 0xFF;

    //Set window Y dimensions
    displayWriteCommand(ST7789_RASET);
    displayWriteData(yStartHigh);
    displayWriteData(yStartLow);
    displayWriteData(yEndHigh);
    displayWriteData(yEndLow);
}
int display24to16Color(int COLOR)
{
    uint8_t redComponent = ((COLOR & 0x00FF0000)>>19);
    uint8_t greenComponent = ((COLOR & 0x0000FF00)>>10);
    uint8_t blueComponent = ((COLOR & 0x000000FF)>>3);
    uint16_t newColor = ((redComponent<<11)|(greenComponent<<5))|(blueComponent);
    return newColor;
}
void displayClear(void)
{
    displaySetWindow(ST7789_XSTART,ST7789_WIDTH,ST7789_YSTART,ST7789_HEIGHT);
    for(int i = 0; i<(ST7789_WIDTH-ST7789_XSTART)*(ST7789_HEIGHT-ST7789_YSTART)*2;i++)
    {
        displayWriteData(0x00);
    }
}
void displayClearBuf(void)
{
    uint8_t writeBuffer[SPI_WRITE_BUFFER_SIZE] = {0};
    displaySetWindow(ST7789_XSTART,ST7789_WIDTH,ST7789_YSTART,ST7789_HEIGHT);
    for(int i = 0; i<(((ST7789_WIDTH-ST7789_XSTART)*(ST7789_HEIGHT-ST7789_YSTART)*2)/SPI_WRITE_BUFFER_SIZE);i++)
    {
            for(int j=0;j<SPI_WRITE_BUFFER_SIZE;j++)
            {
                    writeBuffer[j]=0x00;
            }
            displayWriteDataBuf(writeBuffer,SPI_WRITE_BUFFER_SIZE);
    }
}
void displayFillScreen(int COLOR)
{
    uint8_t colorHigh = COLOR >> 8;
    uint8_t colorLow = COLOR & 0xFF;
    displaySetWindow(ST7789_XSTART,ST7789_WIDTH,ST7789_YSTART,ST7789_HEIGHT);
    for(int i = 0; i<(ST7789_WIDTH-ST7789_XSTART)*(ST7789_HEIGHT-ST7789_YSTART);i++)
    {
        displayWriteData(colorHigh);
        displayWriteData(colorLow);
    }
}
void displayFillScreenBuf(int COLOR)
{
    uint8_t colorHigh = COLOR >> 8;
    uint8_t colorLow = COLOR & 0xFF;
    uint8_t writeBuffer[SPI_WRITE_BUFFER_SIZE] = {0};
    displaySetWindow(ST7789_XSTART,ST7789_WIDTH,ST7789_YSTART,ST7789_HEIGHT);
    for(int i = 0; i<(((ST7789_WIDTH-ST7789_XSTART)*(ST7789_HEIGHT-ST7789_YSTART)*2)/SPI_WRITE_BUFFER_SIZE);i++)
    {
            for(int j=0;j<SPI_WRITE_BUFFER_SIZE-1;j+=2)
            {
                    writeBuffer[j]=colorHigh;
                    writeBuffer[j+1]=colorLow;
            }
            displayWriteDataBuf(writeBuffer,SPI_WRITE_BUFFER_SIZE);
    }
}
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

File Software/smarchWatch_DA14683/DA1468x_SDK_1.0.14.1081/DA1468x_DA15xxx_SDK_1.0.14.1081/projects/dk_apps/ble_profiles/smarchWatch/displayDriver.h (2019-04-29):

/*
 * displayDriver.h
 *
 *  Created on: Jan 15, 2019
 *      Author: samsonm
 */

#ifndef DISPLAYDRIVER_H_
#define DISPLAYDRIVER_H_

#define SPI_WRITE_BUFFER_SIZE 2880 //240*240*2/40 = 2880 which is also 6 lines per write

#define SPI_DELAY       0

#define BYTES_PER_PIXEL 2

#define ST7789_WIDTH    240
#define ST7789_HEIGHT   240
#define ST7789_HEIGHT_OFFSET 40

#define ST7789_XSTART 0
#define ST7789_YSTART 0

//Command registers
#define ST7789_NOP          0x00
#define ST7789_SWRESET      0x01
#define ST7789_SLPIN        0x10
#define ST7789_SLPOUT       0x11
#define ST7789_PTLON        0x12
#define ST7789_NORON        0x13
#define ST7789_INVOFF       0x20
#define ST7789_INVON        0x21
#define ST7789_DISPOFF      0x28
#define ST7789_DISPON       0x29
#define ST7789_CASET        0x2A
#define ST7789_RASET        0x2B
#define ST7789_RAMWR        0x2C
#define ST7789_PTLAR        0x30
#define ST7789_TEON         0x35
#define ST7789_MADCTL       0x36
#define ST7789_IDMOFF       0x38
#define ST7789_IDMON        0x39
#define ST7789_COLMOD       0x3A
#define ST7789_RAMWRC       0x3C
#define ST7789_PORCTRL      0xB2
#define ST7789_GCTRL        0xB7
#define ST7789_VCOMS        0xBB
#define ST7789_LCMCTRL      0xC0
#define ST7789_VDVVRHEN     0xC2
#define ST7789_VRHS         0xC3
#define ST7789_VDVS         0xC4
#define ST7789_FRCTRL2      0xC6
#define ST7789_PWCTRL1      0xD0
#define ST7789_CMD2EN       0xDF
#define ST7789_PVGAMCTRL    0xE0
#define ST7789_NVGAMCTRL    0xE1

#define ST7789_WRDISBV 0X51
#define ST7789_WRCTRLD 0X53

//Display orientations
#define ST7789_MADCTL_MY  0x80
#define ST7789_MADCTL_MX  0x40
#define ST7789_MADCTL_MV  0x20
#define ST7789_MADCTL_ML  0x10
#define ST7789_MADCTL_RGB 0x00

//Color definitions
#define DISPLAY_BLACK   0x0000
#define DISPLAY_BLUE    0x001F
#define DISPLAY_RED     0xF800
#define DISPLAY_GREEN   0x07E0
#define DISPLAY_CYAN    0x07FF
#define DISPLAY_MAGENTA 0xF81F
#define DISPLAY_YELLOW  0xFFE0
#define DISPLAY_WHITE   0xFFFF

//Bitmap offsets
#define BITMAP_SIZE_OFFSET 0x0002
#define BITMAP_DATA_OFFSET 0x000A
#define BITMAP_WIDTH_OFFSET 0x0012
#define BITMAP_HEIGHT_OFFSET 0x0016

void displayInit(void);
void displayWriteCommand(int COMMAND);
void displayWriteData(int DATA);
void displayWriteDataBuf(uint8_t DATA[], int DATA_SIZE);
void displaySetRotation(int ORIENTATION);
void displaySetColumn(int XSTART, int XEND);
void displaySetRow(int YSTART, int YEND);
void displaySetWindow(int XSTART, int XEND, int YSTART, int YEND);
void displaySetWindow2(int XSTART, int XEND, int YSTART, int YEND);
int  display24to16Color(int COLOR);
void displayClear(void);
void displayClearBuf(void);
void displayFillScreen(int COLOR);
void displayFillScreenBuf(int COLOR);
void displayDrawPixel(int X_LOCATION, int Y_LOCATION, int COLOR);
void displayDrawPixelThickness(int X_LOCATION, int Y_LOCATION, int COLOR, int THICKNESS);
void displayDrawLine(int START_X, int END_X, int START_Y, int END_Y, int COLOR);
void displayDrawLinePolar(int START_X, int START_Y, int RADIUS, int ANGLE, int COLOR);
void displayDrawLineThickness(int START_X, int END_X, int START_Y, int END_Y, int COLOR, int THICKNESS);
void displayDrawLineThickness2(int START_X, int END_X, int START_Y, int END_Y, int COLOR, int THICKNESS);
void displayDrawLinePolarThickness(int START_X, int START_Y, int RADIUS, int ANGLE, int COLOR, int THICKNESS);
void displayDrawRectangle(int XSTART, int XEND, int YSTART, int YEND, int COLOR);
void displayDrawRectangleBuf(int XSTART, int XEND, int YSTART, int YEND, int COLOR);
void displayDrawCircle(int CENTER_X, int CENTER_Y, int RADIUS, int COLOR);
void displayTestPattern(void);
void displayTestPattern2(void);
void displayArrayBuf(int XSTART, int WIDTH, int YSTART, int HEIGHT, int (*ARRAY)[], int SIZE_OF_ARRAY);
void displayImageFromMemory(int XSTART, int YSTART, int ADDRESS_IN_MEMORY);
void displayPartialImageFromMemory(int SCREEN_XSTART, int SCREEN_YSTART, int IMAGE_XSTART, int IMAGE_YSTART, int IMAGE_PARTIAL_WIDTH, int IMAGE_PARTIAL_HEIGHT, int ADDRESS_IN_MEMORY);

/*int getSizeOfImage(char *FILENAME, int NAME_SIZE);
int getDataOffsetBMP(char *FILENAME, int NAME_SIZE);
int getHeightOfBMP(char *FILENAME, int NAME_SIZE);
int getWidthOfBMP(char *FILENAME, int NAME_SIZE);

void displayDrawBMP(int START_X, int START_Y, char *FILENAME, int NAME_SIZE);
void displayDrawBMPClearBackground(int START_X, int START_Y, char *FILENAME, int NAME_SIZE, int BACKGROUND_COLOR);
void displayDrawBMPPartial(int START_X, int START_Y, int END_X, int END_Y, char *FILENAME, int NAME_SIZE);
void displayDrawBMPFast(int START_X, int START_Y, char *FILENAME, int NAME_SIZE, int NUMBER_OF_DIVISIONS);
void displayDrawBMPPartialFast(int START_X, int START_Y, int END_X, int END_Y, char *FILENAME, int NAME_SIZE, int NUMBER_OF_DIVISIONS);
void displayDrawBMPFastClearBackground(int START_X, int START_Y, char *FILENAME, int NAME_SIZE, int BACKGROUND_COLOR, int NUMBER_OF_DIVISIONS);
void displayDrawBMPPixel(int X_POSITION_DISPLAY, int Y_POSITION_DISPLAY, int X_POSITION_FILE, int Y_POSITION_FILE, char *FILENAME, int NAME_SIZE);
void displayDrawLineOfBMP(int START_X, int END_X, int START_Y, int END_Y, char *FILENAME, int NAME_SIZE);
void displayDrawLinePolarOfBMP(int START_X, int START_Y, int RADIUS, int ANGLE, char *FILENAME, int NAME_SIZE);
void displayDrawLinePolarThicknessOfBMP(int START_X, int START_Y, int RADIUS, int ANGLE, int THICKNESS, char *FILENAME, int NAME_SIZE);
*/

#endif /* DISPLAYDRIVER_H_ */

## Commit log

2019-05-01 Added a screenshot of the board parameters
2019-05-10 Added step files for body housings
    [bodyBottom22mm_3.stp, bodyTop22mm_3.stp]
2019-05-16 Added native altium files
    [Actuators.SchDoc, BLE.SchDoc, Display.SchDoc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]
